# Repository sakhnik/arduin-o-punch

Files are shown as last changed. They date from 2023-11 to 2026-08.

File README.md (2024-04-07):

# Arduin-o-punch

Icon

Arduino-based punching for orienteering with Mifare NFC cards.

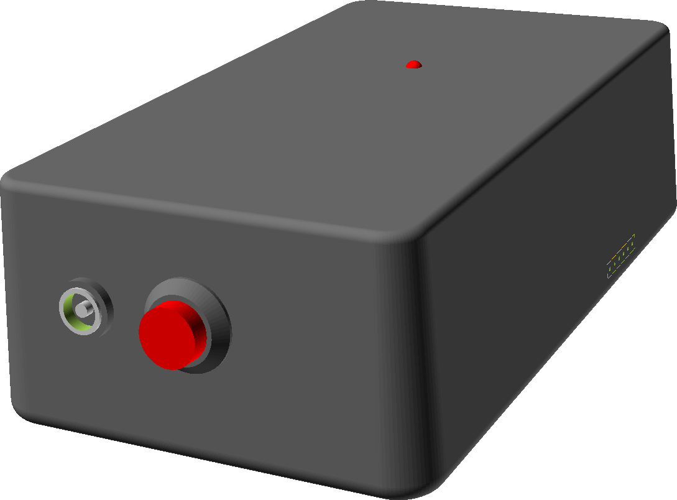
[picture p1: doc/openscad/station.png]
OpenSCAD rendering


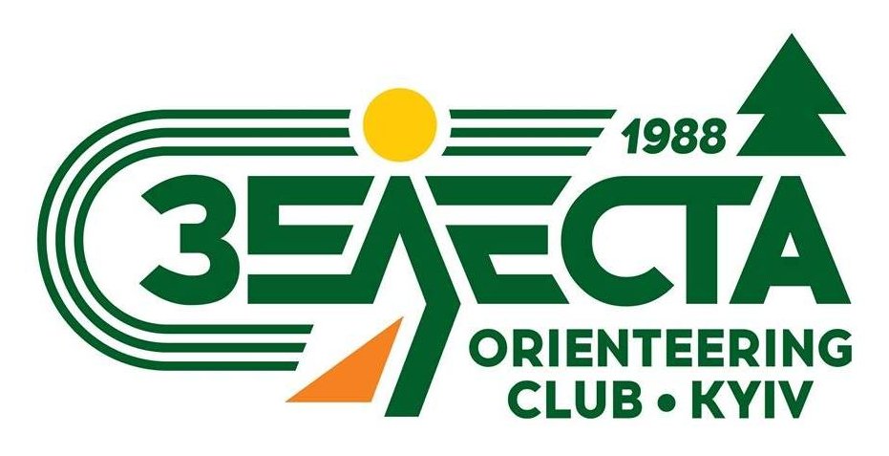
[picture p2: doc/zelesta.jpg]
Зелеста


[Facebook: ZELESTAclub](https://www.facebook.com/ZELESTAclub)

In development. The progress can be followed in the YouTube playlist:
[Arduin-o-punch](https://www.youtube.com/playlist?list=PLd7V290LAw4xda5NdMdNRS0adNVE-jHjh).

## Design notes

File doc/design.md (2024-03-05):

# Arduin-o-punch — custom orienteering punching system built with Arduino

## Components

* MIFARE Classic 1k tags/cards for runners
* Base stations built with Arduino and MFRC 522 RFID reader/writer
* Configuration station: base station + serial interface + PC application
* Android application for card formatting, readout and punches upload:
    [guide](https://developer.android.com/guide/topics/connectivity/nfc/nfc).

## Operation modes

### Arduino station configuration

A high precision RTC clock DS3231 is used backed with CR2032 battery. A station
must be configured with the number, actual crypto key using built in CLI via UART.
Clock is also synchronized with CLI using a scripted application taking into account
communication latency.

The crypto key should ideally be changed on every station before competition, the clocks
are to be synchronized too.

### Signaling

Morse code is used by the base station for signaling. See `Buzzer.cpp` for the actual
list of messages. Most notable are the following ones:

- `OK` upon successful startup
- `RTC` upon startup if communication with RTC fails
- `KEY` upon startup if the default encryption key is used (needs changing)
- `.-` successful punch
- `..-` successful punch of two cards at once
- `...-` successful punch of three cards at once
- `..-.` (Morse `F`) when the card can't be punched because it's full

### Card cleaning and setup

* Authorize with the default key
* Update the key with the actual value for all the blocks
* Write the initial directory index
* Confirm operation successful (beep, flash)

### Card punching

In the MIFARE Classic 1k card, there's only 720 bytes available for punches.
Allocating 4 bytes per punch (1 byte station number + 3 bytes for timestamp in
seconds) allows storing at most 180 punches. The actual limit is lower because
one block should be used for directory information.

It turned out that writing to some cards isn't atomic, the block may be left reset
to all `F`, and the information lost. This prompted for a development of a more
resilient data structure.

The Arduino station records a punch with the following procedure:

- One sector is allocated for a write-ahead log (WAL)
- The log doubles information of the most recent punches (two blocks are used)
- Before punching, the WAL blocks are compared with each other to figure out
  the actual state
- If one of the WAL blocks is missing, it gets restored and written back from
  the healthy one
- When the WAL gets full with 4 punches, the next one triggers copying the punches
  to free storage block (1 copy).
- Add a new punch to the WAL
- Write WAL to the two WAL blocks
- Confirm successful punch

If punching is interrupted at any stage, the data remains consistent. Either
the punching succeeded and the runner got a confirmation, or no confirmation
for her to retry.

The same way Android punching should function for the data consistency.

### Card readout

* Read WAL to find out the actual number of punches
* Read all the punches
* Append the most recent punches from the WAL
* Prepare JSON in the qr-o-punch format, upload to Quick Event
* Confirm successful upload (beep, flash)

### Card reset

Configurator should be used to authorize with the actual key and reset the card
to the pristine state, set default encryption keys in all blocks, reset access
bits.
The application could also track the configured cards to collect statistics
about card states.

## Data layout

See `src/PunchCard.h` for the directory layout, and `src/Punch.h` for the punch data.

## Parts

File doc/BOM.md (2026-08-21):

# Bill of material

| Item | Price | Name | Variant |  Link |
|---|---|---|---|---|
| ESP32-C3 | 88.10 ₴ | | | https://www.aliexpress.com/item/1005006406538478.html |
| RC522 | 44.50 ₴ | MFRC 522 | 1 set | https://www.aliexpress.com/item/1005009711061192.html |
| DS3231SN | 57.00 ₴ | | | https://www.aliexpress.com/item/1005004427508473.html |
| Vibr sensor | 4.00 ₴ | SW-18015P | | https://www.aliexpress.com/item/32952461413.html |
| Buzzer | 12.25 ₴ | | | https://www.aliexpress.com/item/1005004478902150.html |
| Led | 0.30 ₴ | | | https://www.aliexpress.com/item/32985163457.html |
| R1 100K | 0.25 ₴ | | | https://imrad.com.ua/ua/smd1206-100k-1--1 |
| R2 1K | 0.20 ₴ | | | https://imrad.com.ua/ua/1206s4f1001t5e-2 |
| R3 100 | 0.25 ₴ | | | https://imrad.com.ua/ua/rc1206fr-07100rl-0 |
| R4, R5 4K7 | 0.70 ₴ | | | https://imrad.com.ua/ua/rc1206fr-074k7l-1 |
| C1 470uF | 4.00 ₴ | | Low ESR | https://imrad.com.ua/ua/jrg-470u-10-1 |
| C2 1uF | 2.40 ₴ | | | https://imrad.com.ua/ua/cc1206kkx7r9bb105-3 |
| C3 100nF | 2.10 ₴ | | | https://imrad.com.ua/ua/cc1206krx7r9bb104-9 |
| PCB | 42.00 ₴ | | | JLCPCB |
| Bat protection | 7.80 ₴ | | 3.2 Lifepo4 | https://www.aliexpress.com/item/1005001732120817.html |
| Lifepo4 cell | 150.00 ₴ | | | https://prom.ua/ua/p2566621781-akumulyatori-litij-zalizo.html |
| Wires | 11.00 ₴ | 24awg | Y 6x4cm, R+B 10cm | https://www.aliexpress.com/item/1005009794836849.html |

Total        426.85 ₴

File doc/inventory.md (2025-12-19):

# 38

  Battery 18350

  - 2025-11-04 CR2032

# 41

  Battery 18350

 * 2025-11-04 CR2032

# 44

  Battery 18650

  - 2025-11-04 CR2032

# 50

  Battery 18350

  - 2025-11-04 CR2032

# 54

  Battery 18350

  - 2025-11-04 CR2032

# 55 pro16

  Battery 18650

  - 2025-11-06 18650

# 57 pro16

# 58 pro16

# 62 pro16

# 63 pro16

  Battery 18650

  - 2025-11-06 18650

# 64 pro16

# 65

  Battery 18350

  - 2025-11-07 GND contact

# 69

  Battery 18650

  - 2025-11-07 Reglue clock
  - 2025-12-05 Solder GND
  - 2025-12-06 Failure GND - lagging

# 70

  Battery 18650

  - 2025-11-04 leaky battery, clock is off
  - 2025-11-06 18650

# 73

  Battery 18650

  - 2025-12-05 Solder GND

# 74

  Battery 18650

  - 2025-11-04 18650
  - 2025-12-06 Solder GND

# 75

  Battery 18650

  - 2025-11-06 18650

# 76

  Battery 18650

  - 2025-11-06 18650
  - 2025-11-07 CR2032
  - 2025-11-13 GND fix
  - 2025-11-22 Solder GND

# 77

  Battery 18650

# 78

  Hard to flash

# 79

  Battery 18650

  - 2025-11-05 CR2032
  - 2025-11-22 Solder GND

# 100

  Battery 18650

  - 2025-12-05 Solder GND, change 18650, replace CR2032

# 255

  Battery 18650

  - 2025-12-05 Solder GND, replace CR2032, change 18650

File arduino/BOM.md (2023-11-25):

# Bill of material

## Common parts

- RFID RC522
- Active buzzer
- LED
- Power Supply 18650 -> 3.3/5v
- Battery 18650
- Wires

## Arduino options

### Nano

- Arduino Nano 5v 16MHz
- Resistor 220R
- 4x Resistors 2k2
- 4x Resistors 1k

## RTC Clock options

### No RTC

Vulnerable to board reset.

### DS3132

Higher precision (TCOX), higher cost.

- RTC DS3132
- Battery 3.7v LIR2032

# Cost estimate

Arduino   75.00
RC522     50.00
18650     75.00
Power     60.00
DS3231    48.00
Wires      8.00
Buzzer     4.00
Led        1.00
R         10.00
Board      5.00
Box       50.00

Total    386.00

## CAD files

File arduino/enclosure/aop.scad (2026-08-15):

include <BOSL2/std.scad>

$fn = 90;

length = 106;
width = 80;
bottom_thickness = 5;
platform_thickness = 4;
lid_height = 25;
lid_thickness = 5;

battery_d = 18.3;
battery_h = 65.3;
battery_y = 32;

pcb_offset_y = 16;  // back
rfid_offset_y = -25; // fwd
rfid_offset_z = lid_height - lid_thickness;
notch_height = 3;

inner_width = width - 2 * lid_thickness;
inner_length = length - 2 * lid_thickness;
inner_height = lid_height - lid_thickness;
screw_x = width * 0.5 - lid_thickness;
screw_y = length * 0.5 - lid_thickness;

module battery() {
    fwd(battery_y)
    cylinder(h=battery_h, r=battery_d/2, anchor=LEFT, orient=LEFT);
}

module pcb_model() {
    pcb_width = 45.3;
    pcb_length = 55.3;
    pcb_height = 7;
    pcb_hole_r = 0.9;
    pcb_hole_offset = 3;
    pcb_led_offset_y = 6;
    pcb_pad_size = 4;
    pcb_pad_offset = 9;
    pcb_wire_width = 4;

    hole_x = pcb_width * 0.5 - pcb_hole_offset;
    hole_y = pcb_length * 0.5 - pcb_hole_offset;
    pad_x = pcb_width * 0.5 - pcb_pad_offset;
    pad_y = pcb_length * 0.5 - pcb_pad_offset;

    difference() {
        union() {
            cuboid([pcb_width, pcb_length, pcb_height], anchor=BOTTOM);

            // hole for the LED
            fwd(pcb_length * 0.5 - pcb_led_offset_y)
                union() {
                    cylinder(h=lid_height, r=1.6, anchor=BOTTOM);
                    up(lid_height)
                        cylinder(h=1, r=2, anchor=TOP);
                }

            // holes for the pad wires
            move([pad_x, -pcb_length * 0.5, 0])
                cuboid([pcb_wire_width, pcb_wire_width, pcb_height], anchor=BOTTOM+BACK);
            move([pcb_width * 0.5, -pad_y, 0])
                cuboid([pcb_wire_width, pcb_wire_width, pcb_height], anchor=BOTTOM+LEFT);

            // holes for the pads
            move([pad_x, -(pcb_length/2 - pcb_pad_size/2 - 1), 0])
                cylinder(h=lid_height, r=1.72, anchor=TOP);
            move([pcb_width/2 - pcb_pad_size/2 - 1, -pad_y, 0])
                cylinder(h=lid_height, r=1.72, anchor=TOP);
        }

        // holes
        //for (dx = [-1:2:1]) {
        //    for (dy = [-1:2:1]) {
        //        move([dx * hole_x, dy * hole_y, 0])
        //        cylinder(h=10, r=pcb_hole_r);
        //    }
        //}

        // notches
        //left(pcb_width/2) up(notch_height)
        //    cylinder(r=1, h=20, anchor=CENTER, orient=FRONT);
        //right(pcb_width/2) up(notch_height)
        //    cylinder(r=1, h=20, anchor=CENTER, orient=FRONT);
    }
}

module pcb() {
    back(pcb_offset_y) zrot(180) pcb_model();
}

module rfid_model() {
    rfid_width = 40;
    rfid_length = 60.5;
    rfid_height = 5;

    rfid_hole_r = 1.5;
    rfid_hole1_offset = 7.5;
    rfid_hole2_offset_x = 3;
    rfid_hole2_offset_y = 16;

    hole1_x = rfid_width/2 - rfid_hole1_offset;
    hole1_y = rfid_length - rfid_hole1_offset;

    hole2_x = rfid_width/2 - rfid_hole2_offset_x;

    difference() {
        cuboid([rfid_width, rfid_length, rfid_height], anchor=TOP+BACK);

        move([hole1_x, -hole1_y, 0])
            cylinder(h=rfid_height+1, r=rfid_hole_r, anchor=TOP);
        move([-hole1_x, -hole1_y, 0])
            cylinder(h=rfid_height+1, r=rfid_hole_r, anchor=TOP);
        move([hole2_x, -rfid_hole2_offset_y, 0])
            cylinder(h=rfid_height+1, r=rfid_hole_r, anchor=TOP);
        move([-hole2_x, -rfid_hole2_offset_y, 0])
            cylinder(h=rfid_height+1, r=rfid_hole_r, anchor=TOP);

        // notches
        //move([-rfid_width/2, -rfid_length/2, -notch_height])
        //    cylinder(r=1, h=20, anchor=CENTER, orient=FRONT);
        //move([rfid_width/2, -rfid_length/2, -notch_height])
        //    cylinder(r=1, h=20, anchor=CENTER, orient=FRONT);
    }
}

module rfid() {
    move([0, rfid_offset_y, rfid_offset_z])
        zrot(180) rfid_model();
}

module screw_support(x, y) {
    move([x, y, 0])
    cylinder(h=inner_height, r=5);

}

module screw_supports() {
    for (dx = [-1:2:1]) {
        for (dy = [-1:2:1]) {
            screw_support(dx * screw_x, dy * screw_y);
        }
        screw_support(dx * screw_x, 0);
    }
}

module lid_shell() {
    difference() {
        cuboid(
            [width, length, lid_height],
            rounding=5,
            edges=[FRONT+LEFT, FRONT+RIGHT, BACK+LEFT, BACK+RIGHT, TOP],
            anchor=BOTTOM
        );

        down(1)
        cuboid(
            [inner_width, inner_length, 1 + inner_height],
            rounding=5,
            edges=[FRONT+LEFT, FRONT+RIGHT, BACK+LEFT, BACK+RIGHT],
            anchor=BOTTOM
        );
    }
}

module outer_lid() {
    lid_shell();
    screw_supports();
    // battery+rfid support
    up(inner_height)
    cuboid([inner_width, inner_length, platform_thickness], anchor=TOP);
};

module screw_hole(x, y) {
    move([x, y, 0])
    cylinder(h=lid_height-lid_thickness+bottom_thickness, r1=1.72, r2=0.7);

    // Counter sink
    move([x, y, 0])
    cylinder(h=2.5, r1=3.5, r2=1, anchor=BOTTOM);
}

module screw_holes() {
    for (dx = [-1:2:1]) {
        for (dy = [-1:2:1]) {
            screw_hole(dx * screw_x, dy * screw_y);
        }
        screw_hole(dx * screw_x, 0);
    }
}

module lid() {
    difference() {
        outer_lid();

        down(bottom_thickness) screw_holes();
        battery();
        pcb();
        rfid();

        // Optional: a cable hole
        //cable_r = 2.5;

        //left(width/2) back(10) up(platform_thickness + cable_r)
        //union() {
        //    cylinder(h=lid_thickness*2, r=cable_r, orient=LEFT, anchor=CENTER);
        //    cuboid([lid_thickness*2, cable_r*2, bottom_thickness+platform_thickness], anchor=TOP);
        //}
    }
}

module base() {
    difference() {
        union() {
            cuboid(
                [width, length, bottom_thickness],
                rounding=5,
                edges=[FRONT+LEFT, FRONT+RIGHT, BACK+LEFT, BACK+RIGHT],
                anchor=TOP
            );

            cuboid(
                [inner_width, inner_length, platform_thickness],
                anchor=BOTTOM
            );
        }

        screw_supports();
        battery();
        pcb();

        down(bottom_thickness)
            screw_holes();
    }
}

base();

right(100)
    lid();

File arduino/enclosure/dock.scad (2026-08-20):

include <BOSL2/std.scad>

$fn = 90;

module pcb() {

    pcb_length = 30;
    pcb_width = 15.2;

    cuboid([pcb_width, pcb_length, 10], anchor=BOTTOM);

    // usb
    fwd(pcb_length/2 + 2.5) up(0.5)
    cuboid([9.5, 9.5, 3.5], edges=[LEFT+BOTTOM,RIGHT+BOTTOM], rounding=1.4, anchor=TOP+FRONT);

    fwd(1.5) left(3.5)
    cuboid([8.2, 8.2, 4], anchor=TOP);

    back(5)
    cuboid([pcb_width, pcb_length - 10, 2], anchor=TOP);

    back(pcb_length/2)
    cuboid([20, 15, 7], anchor=BOTTOM);

    right(pcb_width/2) back(pcb_length/2-4)
    cuboid([2, 5, 16], anchor=TOP+RIGHT+BACK);
}

difference() {

    back(15)
    cuboid([40, 70, 16], rounding=1.4);

    fwd(2.5)
    pcb();

    left(4) back(55) up(3.5)
    zrot(45)
    cuboid(
        [80, 106, 100],
        rounding=5,
        edges=[FRONT+LEFT, FRONT+RIGHT, BACK+LEFT, BACK+RIGHT],
        anchor=BOTTOM
    );
}

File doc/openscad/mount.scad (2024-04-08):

include <station.scad>

module planck() {
    translate([0, 0, -15])
        cube([bottom_width, bottom_length * 2, 30], center = true);
}

holder_length = 20;
holder_thickness = 2;
holder_depth = 20;

holder_height = height + holder_depth + holder_thickness;

module holder() {
    color("Silver")
        translate([0, 0, holder_height / 2 - holder_depth])
        union() {
            // Overhead bracket
            difference() {
                cube([bottom_width + holder_thickness, holder_length, holder_height], center=true);
                cube([bottom_width, holder_length + 10, holder_height - holder_thickness], center=true);
            }
            translate([0, -holder_length * 0.5, holder_height * 0.5 - holder_depth + holder_thickness * 0.5])
                // Front plate
                difference() {
                    cube([bottom_width, holder_thickness, height], center=true);
                    // Hole for the switch
                    translate([0, holder_thickness, 0]) rotate([90, 0, 0]) cylinder(h = holder_thickness * 4, r = 2);
                    // Hole for the charger plug
                    translate([-bottom_width * 0.2, holder_thickness, 0]) rotate([90, 0, 0]) {
                        hull() {
                            cylinder(h = holder_thickness * 4, r = 5);
                            translate([-8, 0, 0]) cylinder(h = holder_thickness * 4, r = 5);
                        }
                    }
                }
            // Bottom plate (apron)
            translate([0, -holder_length, -holder_depth * 0.5 + holder_thickness])
                cube([bottom_width, holder_length, holder_thickness], center=true);
        }

}

planck();

translate([0, -bottom_length * 0.5 + corner_radius, 0])
    holder();

translate([0, bottom_length * 0.5 - 2 * corner_radius, 0])
    rotate([0, 0, 180]) holder();

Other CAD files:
doc/openscad/station.scad

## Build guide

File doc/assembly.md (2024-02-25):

# How to assemble an Arduino station

[Українською](assembly.uk.md)

| Step | Reference picture |
|---|---|
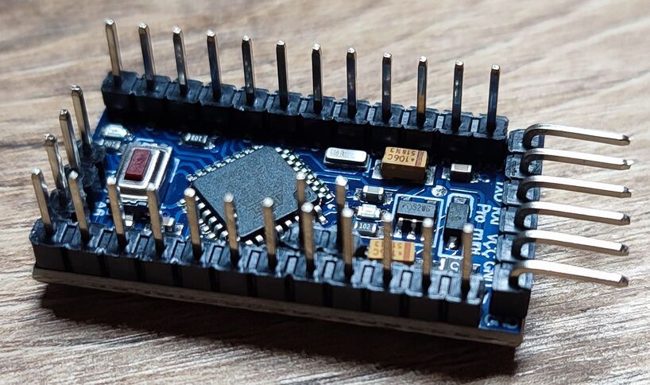
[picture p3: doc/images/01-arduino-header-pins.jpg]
| Solder header pins to the face surface of Arduino Pro Mini  |  |
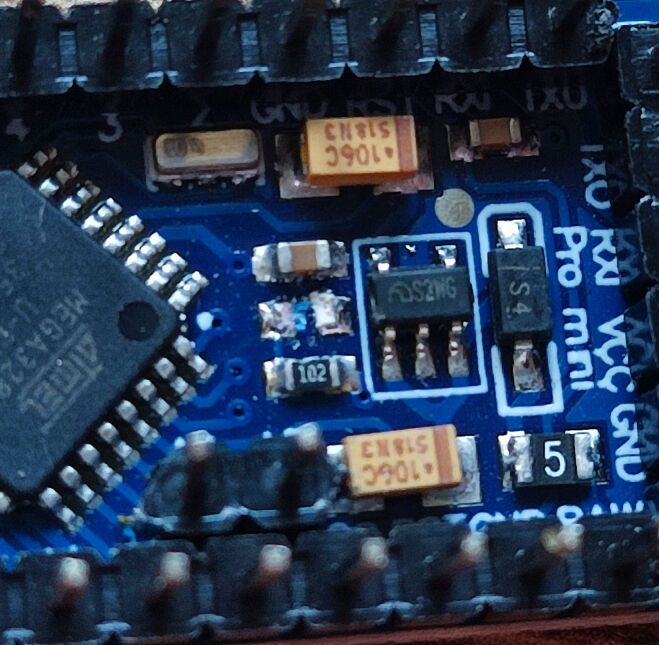
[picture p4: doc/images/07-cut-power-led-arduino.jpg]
| Remove power led from Arduino Pro Mini |  |
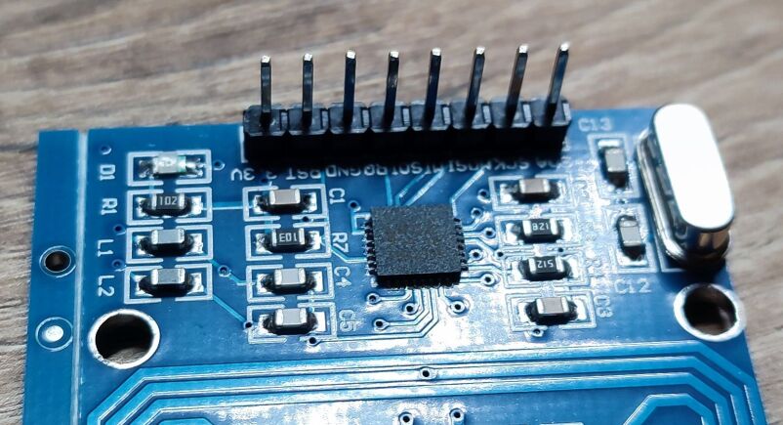
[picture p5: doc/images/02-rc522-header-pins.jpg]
| Solder header pins to the face surface of RC522 |  |
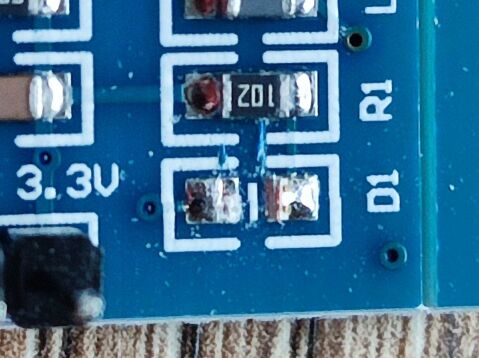
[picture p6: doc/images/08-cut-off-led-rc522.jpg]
| Remove D1 led from RC522 |  |
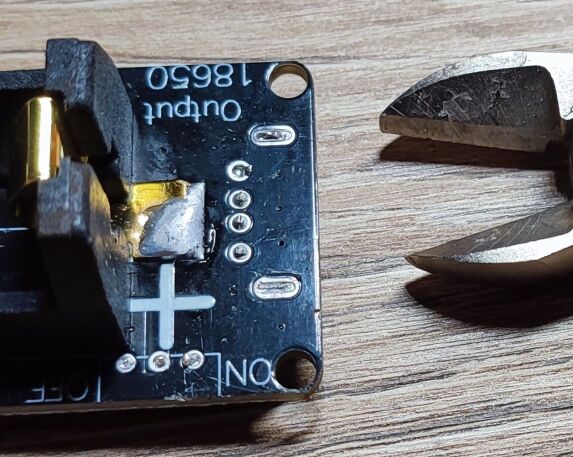
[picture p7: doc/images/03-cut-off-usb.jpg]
| Remove USB output, switch from 18650 power source |  |
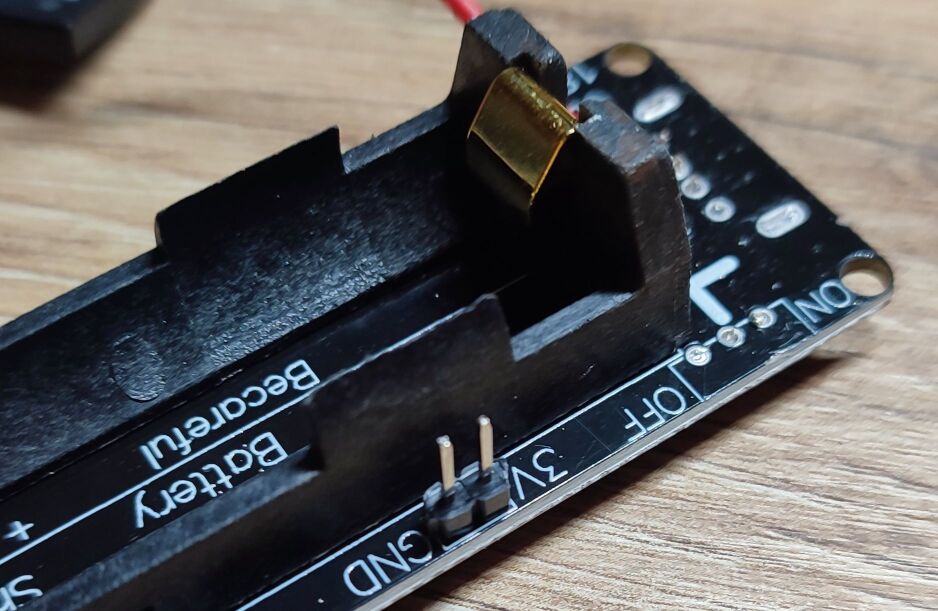
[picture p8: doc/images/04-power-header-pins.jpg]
| Solder header pins to a 3.3v output of 18650 power source |  |
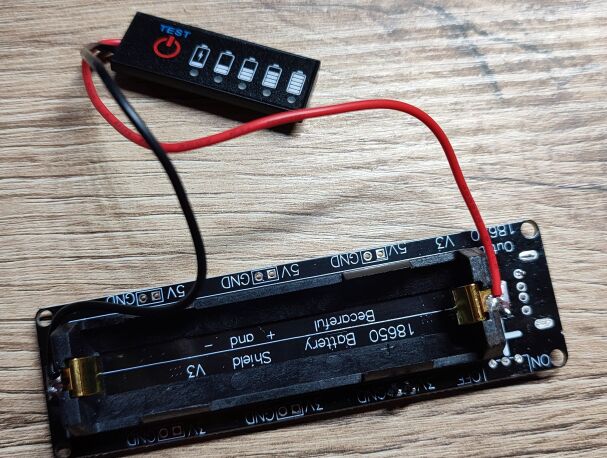
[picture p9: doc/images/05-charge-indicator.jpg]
| Solder indicator to the 18650 pads of 18650 power source |  |
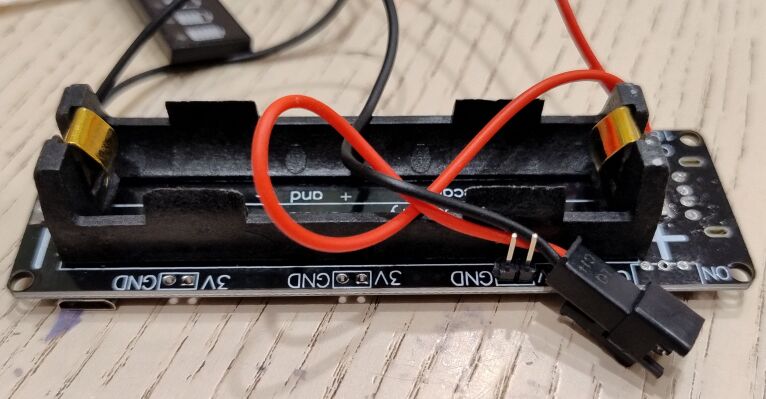
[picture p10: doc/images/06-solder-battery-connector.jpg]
| Solder JST 2-pin battery connector |  |
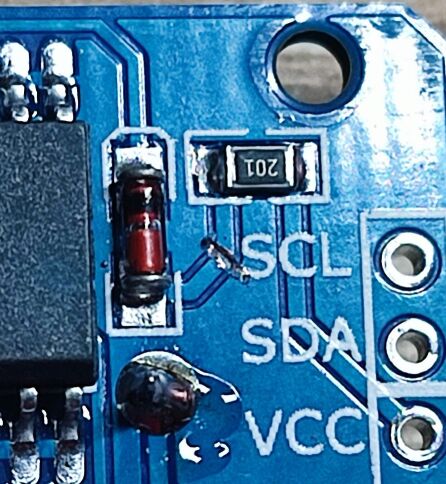
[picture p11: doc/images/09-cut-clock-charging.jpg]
| Cut the charging circuit of DS3231 to allow using non-rechargable CR2032 |   |
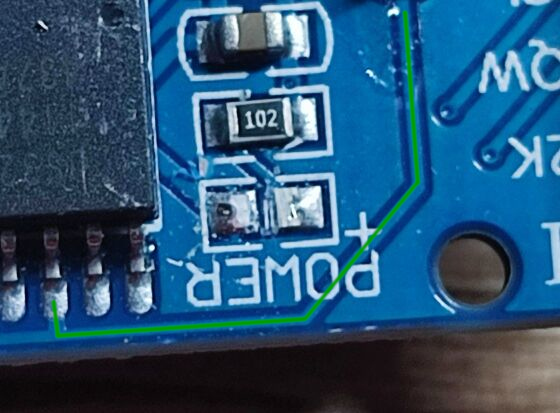
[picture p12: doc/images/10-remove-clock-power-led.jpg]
| Remove power led from DS3231. Be careful not to break the trace from Bat+ to the pin 14 of the IC! |   |
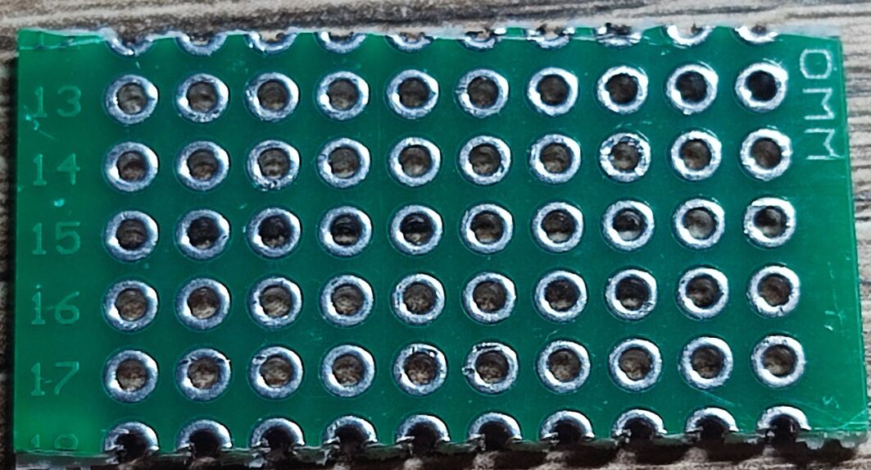
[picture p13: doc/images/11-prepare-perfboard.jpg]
| Prepare perfboard approximately 10x5 holes |  |
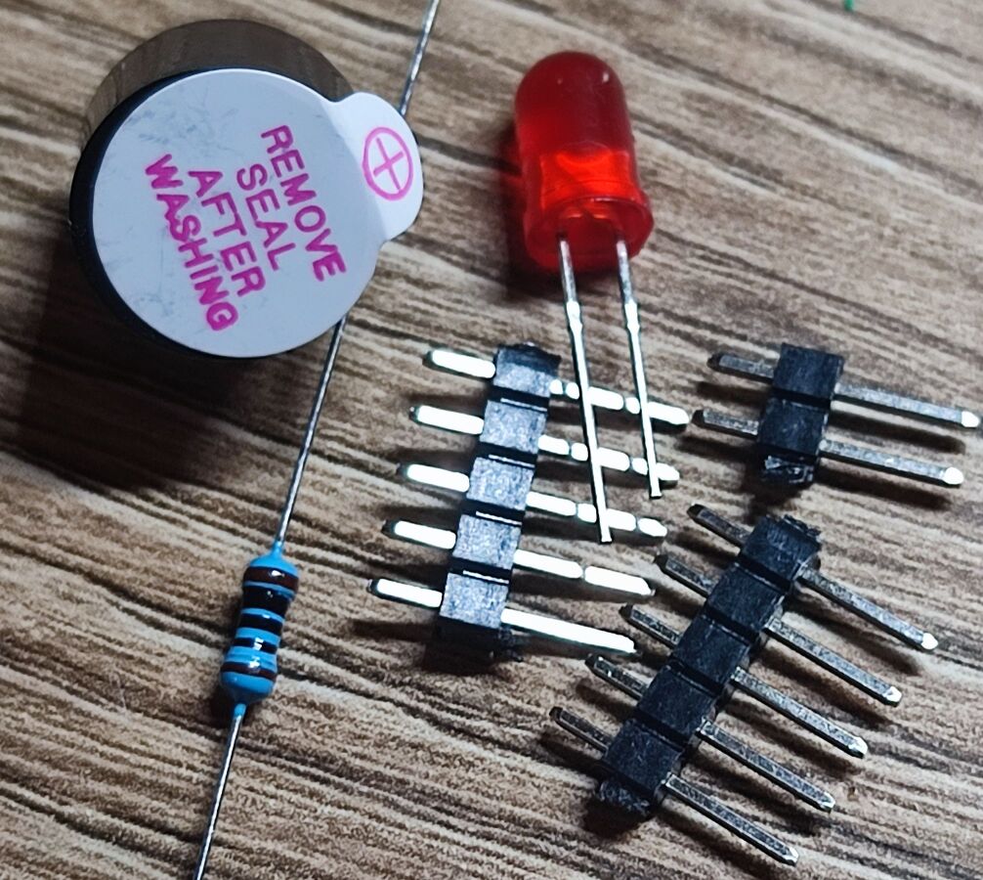
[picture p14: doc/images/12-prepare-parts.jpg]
| Prepare the required parts: led, active buzzer for 3.3v (5v will also work), 100Ω, 2 5x1 pin headers and a pin header 2x1  |   |
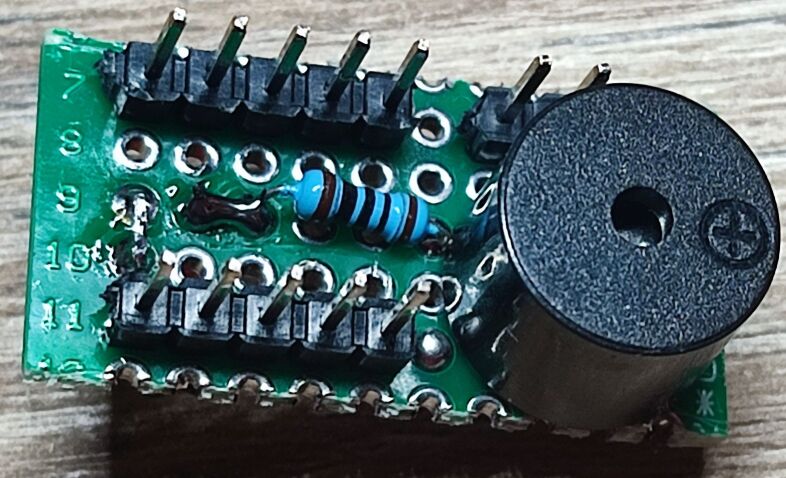
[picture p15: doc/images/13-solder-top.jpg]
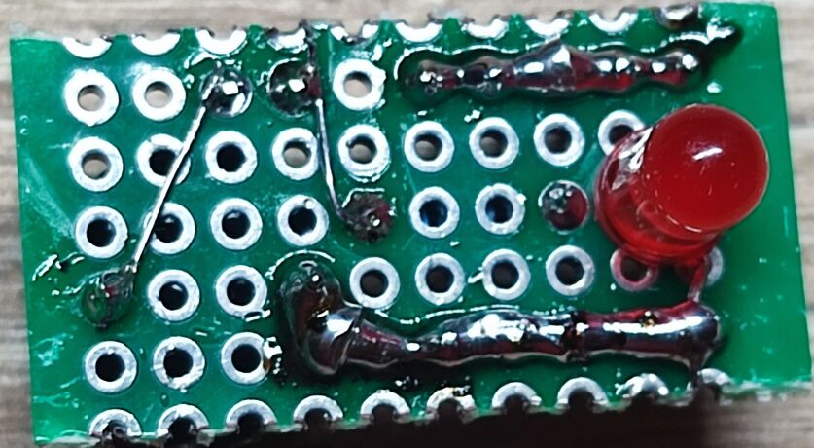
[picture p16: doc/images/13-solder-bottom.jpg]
| Solder the parts onto the perfboard (scheme below) |  |
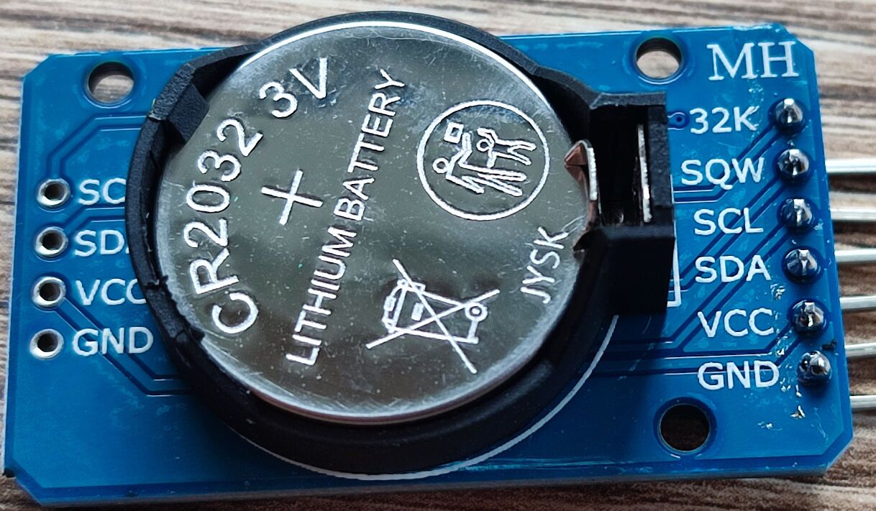
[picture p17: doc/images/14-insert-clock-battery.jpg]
| Insert backup battery CR2032 into the clock module |  |
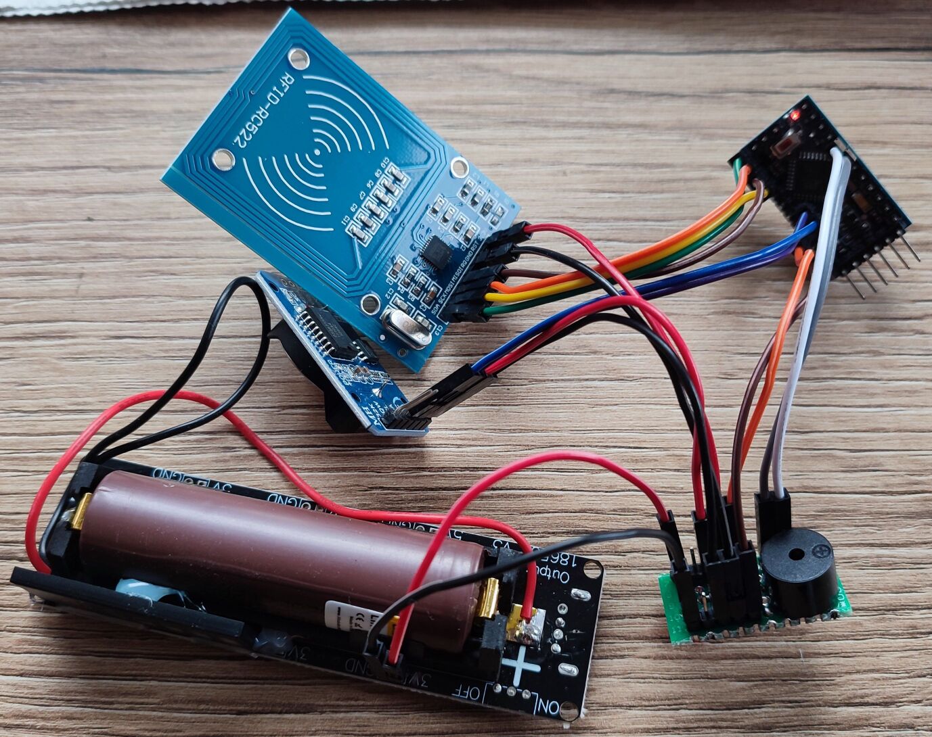
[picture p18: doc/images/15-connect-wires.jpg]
| Connect wires between modules (scheme below) |  |
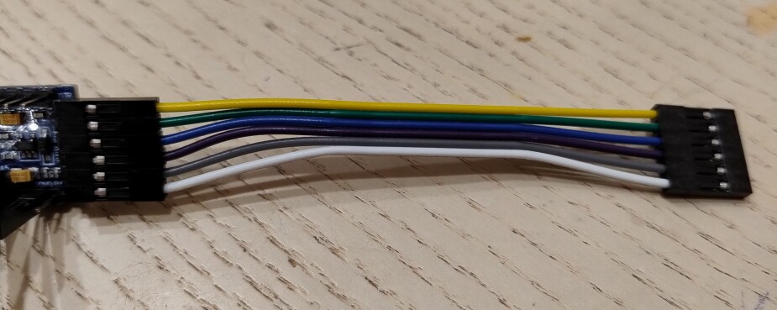
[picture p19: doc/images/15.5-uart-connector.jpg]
| Prepare UART 6P Dupont connector |  |
| Upload the firmware and test (the procedure below) | |

## Soldering scheme

* Two pin headers for negative and positive rails
* Led is placed close to the proximal end on the bottom side, the cathode connected to the negative rail
* Led's anode connected to the resistor 100Ω
* The other end of the resistor to one of the signal pins
* The other signal pin to the positive terminal of the buzzer
* The negative terminal of the buzzer connected to the negative rail

## Wiring scheme

* Clock DS3231: SDA, SCL → A4, A5
* NFC reader RC522: SS, SCK, MOSI, MISO → 10, 13, 11, 12
* Led and buzzer: 4, 5
* All GND to the ground rail of the perfboard with black wires
* All VCC 3.3v to the power rail of the perfboard with red wires
* Power source: GND → ground rail, 3.3v → power rail

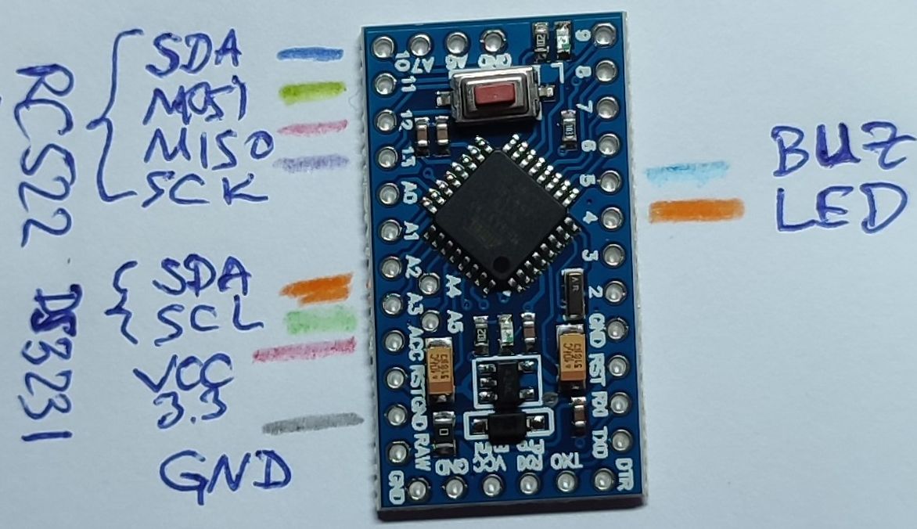
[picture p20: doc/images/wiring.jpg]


The switch the station off, disconnect a wire from the power source.

## Test procedure

* Synchronize the clock
* Configure station id, encryption key
* Punch a test card and verify the punch
* Switch the station off (disconnect from the power source)
* Wait a minute
* Switch the station on
* Check the clock stays set
* Punch a test card and verify the punch

## Encasing

| Step | Reference picture |
|---|---|
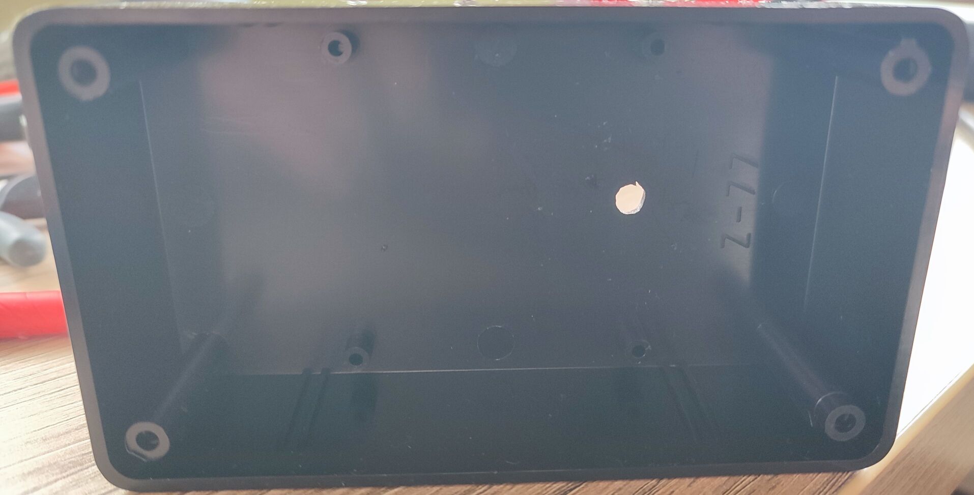
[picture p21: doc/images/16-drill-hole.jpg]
| Drill a hole for LED (3mm or 5mm) |  |
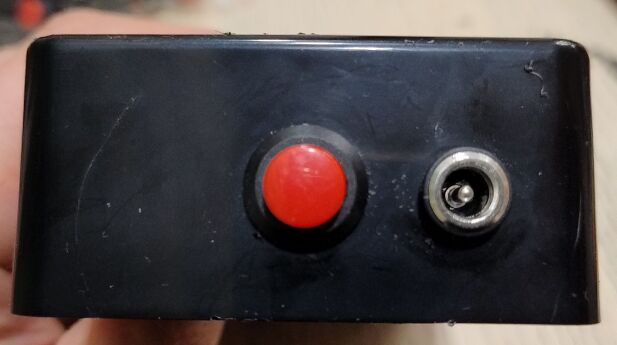
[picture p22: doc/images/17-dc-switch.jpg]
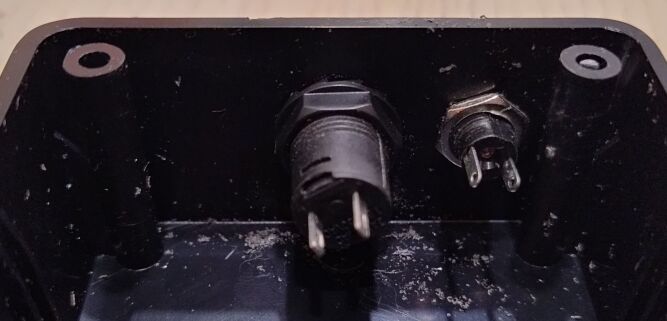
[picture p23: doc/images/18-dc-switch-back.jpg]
| Drill holes for the switch and DC charger input. | <br/>  |
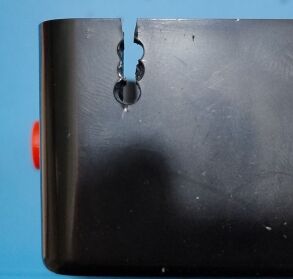
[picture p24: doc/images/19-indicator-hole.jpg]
| Drill and cut a hole for indicator wires |  |
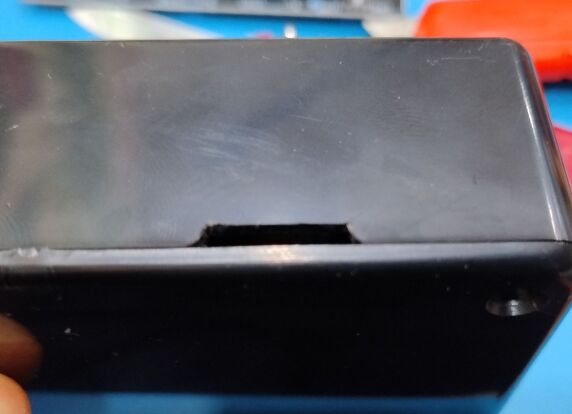
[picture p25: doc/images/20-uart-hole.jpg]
| Cut a hole for UART connector 6P Dupont |  |
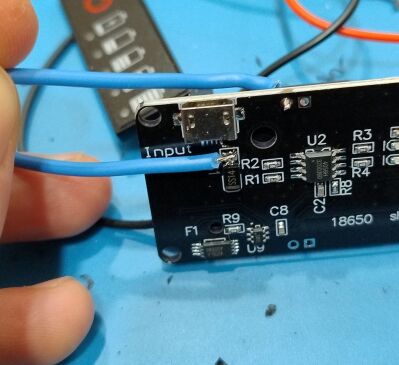
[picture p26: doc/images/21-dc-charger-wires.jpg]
| Solder charger wires GND and 5.2V as shown |  |
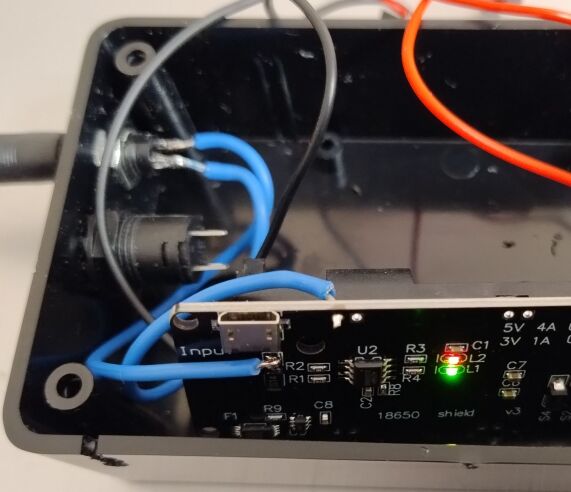
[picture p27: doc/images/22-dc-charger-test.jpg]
| Solder the wires to the DC input and test |  |
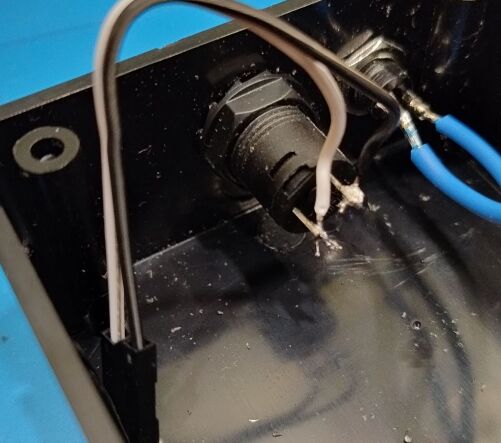
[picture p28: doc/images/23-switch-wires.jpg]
| Solder the connector wires to the switch |  |
| Connect the battery and power lines temorarily and test functionality | |
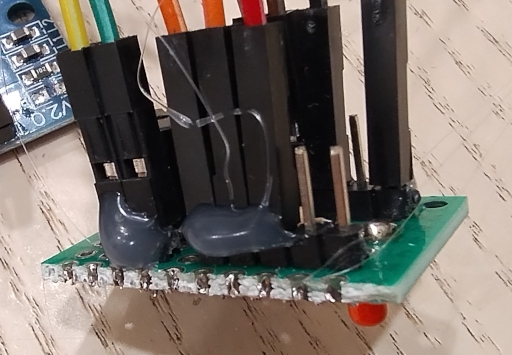
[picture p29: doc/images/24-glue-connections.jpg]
| Fasten Dupont connectors with glue |  |
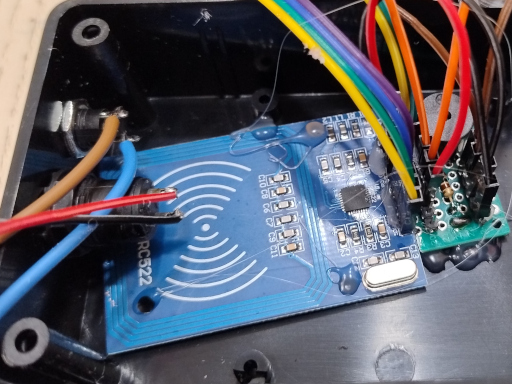
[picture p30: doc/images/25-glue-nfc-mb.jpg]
| Glue NFC reader and motherboard fitting the LED into the hole |  |
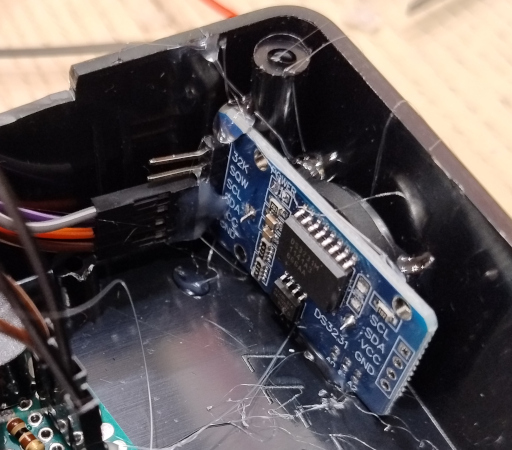
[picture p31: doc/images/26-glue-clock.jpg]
| Glue the clock |  |
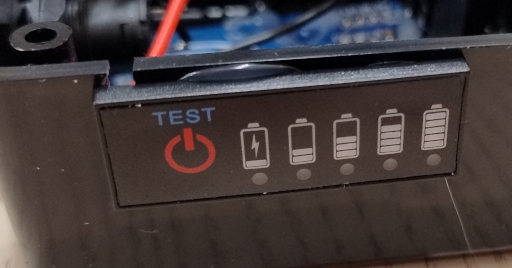
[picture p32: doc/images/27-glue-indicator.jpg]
| Glue power indicator to the outer side |  |
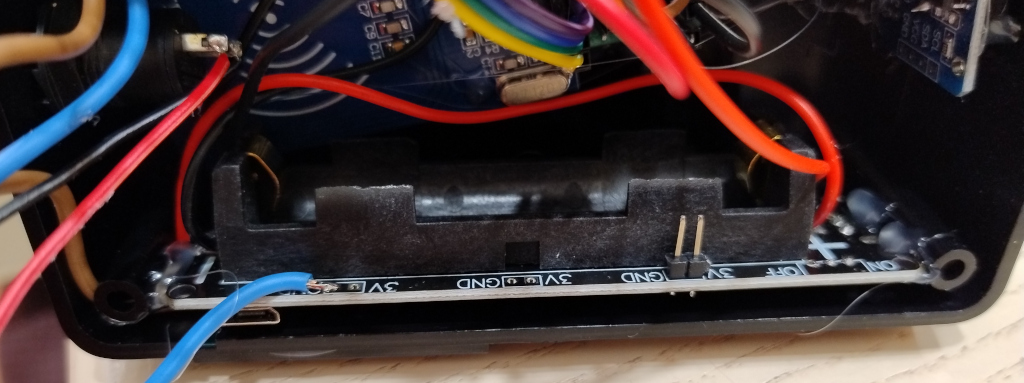
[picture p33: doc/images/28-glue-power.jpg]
| Glue the power adapter |  |
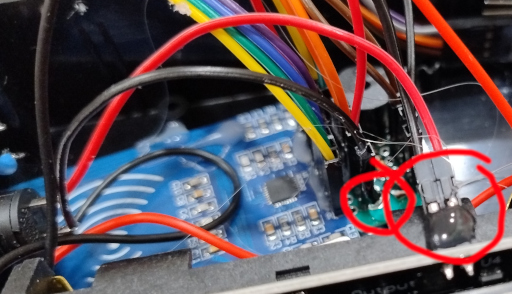
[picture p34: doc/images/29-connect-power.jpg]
| Connect the power lines to the motherboard |  |
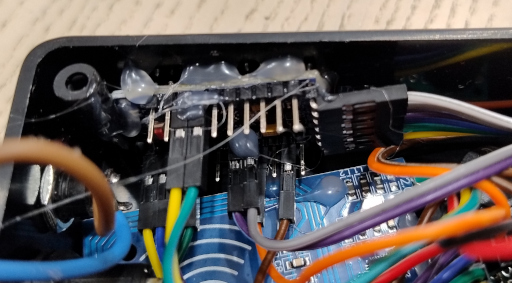
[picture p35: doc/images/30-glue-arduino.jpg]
| Glue the Arduino controller to the side wall |  |
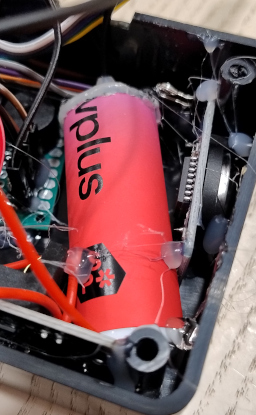
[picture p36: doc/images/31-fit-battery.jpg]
| Fit vape battery into the free space (or insert 18650 into the holder) |  |
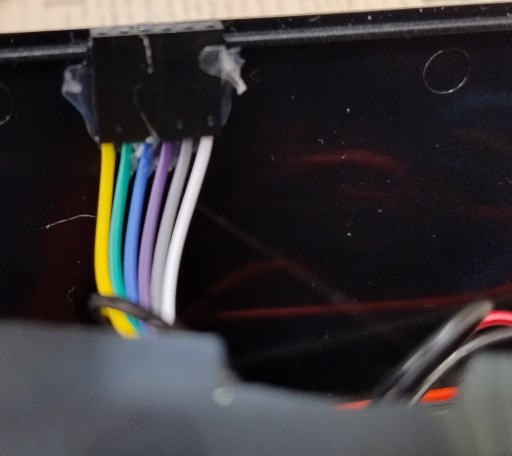
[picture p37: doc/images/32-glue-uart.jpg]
| Glue UART connector to the slit in the lid |  |
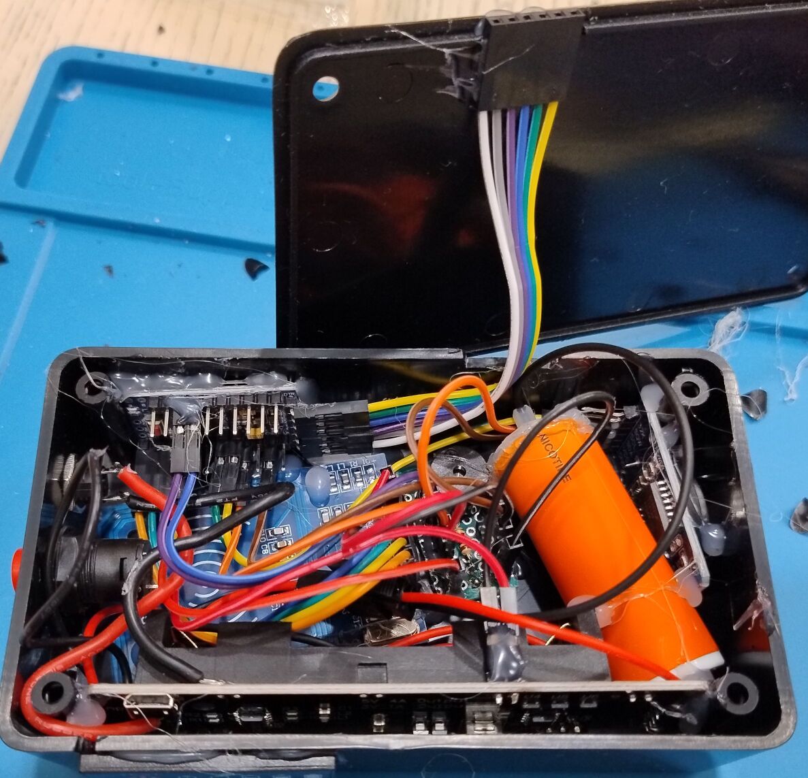
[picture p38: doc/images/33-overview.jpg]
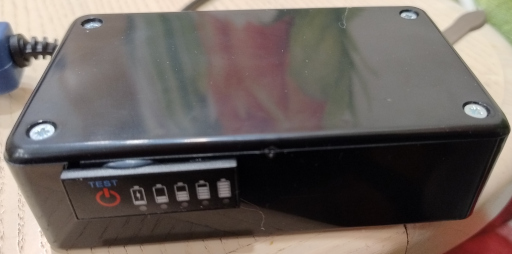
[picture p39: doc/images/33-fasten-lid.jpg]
| Close the lid and fasten with the screws | <br/>  |

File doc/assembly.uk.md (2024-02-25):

# Як зібрати станцію Arduino

[English](assembly.md)

| Крок | Ілюстрація |
|---|---|
| Припаяти виводи на лицевий бік Arduino Pro Mini |  |
| Прибрати індикатор живлення з Arduino Pro Mini |  |
| Припаяти виводи на лицевий бік RC522 |  |
| Прибрати світлодіод D1 з RC522 |  |
| Прибрати вивід USB, вимикач з джерела живлення 18650 |  |
| Припаяти виводи до виходу 3.3 В джерела живлення 18650 |  |
| Припаяти індикатор заряду до полюсів 18650 |  |
| Припаяти конектор JST-2 для під’єднання батареї |  |
| Розірвати ланцюг заряджання DS3231 щоб застосувати незаряджуваний елемент CR2032 |   |
| Прибрати індикатор живлення з DS3231. Обережно, щоб не пошкодити доріжку від Bat+ до виходу 14 мікросхеми! |   |
| Підготувати макетну плату розміром приблизно 10x5 отворів |  |
| Підготувати необхідні деталі: світлодіод, активну пищалку на 3.3 В (5 В також підійде), 100Ω, 2 виводи 5x1 і один вивід 2x1  |   |
| Припаяти деталі на макетну плату (схема нижче) |  |
| Встановити резервний елемент живлення CR2032 в модуль годинника |  |
| З’єднати модулі проводами (схема нижче) |  |
| Підготувати для UART з’єднувач 6P Дюпон |  |
| Вивантажити програму і перевірити (процедура нижче) | |

## Схема паяння

* Два виводи 5х1 для негативної і позитивної шини
* Світлодіод із зворотного боку з ближчого кінця, катодом до негативної шини
* Анод світлодіода до резистора 100Ω
* Інший кінець резистора до одного із сигнальних виводів
* Інший сигнальний вивід до позитивного терміналу пищалки
* Негативний термінал пищалки до негативної шини

## Схема підключення

* Годинник DS3231: SDA, SCL → A4, A5
* Зчитувач NFC RC522: SS, SCK, MOSI, MISO → 10, 13, 11, 12
* Світлодіод і пищалка: 4, 5
* Всі GND до негативної шини макетної плати чорними проводами
* Всі VCC 3.3 В до позитивної шини макетної плати червоними проводами
* Джерело живлення: GND → негативна шина, 3.3 В → позитивна шина



Для вимкнення станції потрібно від’єднати провід від джерела живлення.

## Процедура тестування

* Синхронізувати годинник
* Сконфігурувати номер станції, код шифрування
* Поставити і перевірити відмітку в тестовій картці
* Вимкнути станцію (від’єднати від джерела живлення)
* Зачекати хвилину
* Увімкнути станцію
* Перевірити, чи годинник показує правильний час
* Поставити і перевірити відмітку в тестовій картці

## Монтування у корпус

| Крок | Ілюстрація |
|---|---|
| Просвердлити отвір для світлодіода (3 мм або 5 мм) |  |
| Просвердлити отвори для вимикача і гнізда заряджання. | <br/>  |
| Просвердлити і вирізати отвір для проводів індикатора |  |
| Вирізати отвір для конектора UART 6P Дюпон |  |
| Припаяти проводи заряджання GND і 5.2 В, як на ілюстрації |  |
| Припаяти проводи до входу DC і перевірити |  |
| Припаяти проводи з конектором до вимикача |  |
| Під’єднати тимчасово акумулятор і проводи живлення, перевірити функціональність | |
| Укріпити з’єднувачі Дюпон клеєм |  |
| Приклеїти зчитувачч і материнську плату, просадивши світлодіод у отвір |  |
| Приклеїти годинник |  |
| Приклеїти індикатор заряду акумулятора на зовнішню стінку |  |
| Приклеїти плату живлення |  |
| Під’єднати проводи живлення до материнської плати |  |
| Приклеїти контролер Arduino до бічної стінки |  |
| Встановити акумулятор від електронної цигарки у вільне місце (або вставити 18650 у тримач) |  |
| Приклеїти з’єднувач UART на кришку біля щілини |  |
| Закрити кришку і закріпити шурупами | <br/>  |

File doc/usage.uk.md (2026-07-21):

# Користування Arduin-O-Punch

<a href="https://www.facebook.com/ZELESTAclub">Зелеста</a>

[Facebook: ZELESTAclub](https://www.facebook.com/ZELESTAclub)

Система відмітки [Arduin-O-Punch](https://github.com/sakhnik/arduin-o-punch)
складається із таких частин:

* мобільний додаток на телефоні з андроїдом
* станції розміром 124 х 72 х 32 мм
* перехідник для конфігурації станцій
* картки для відмітки.

Учасники проходять дистанцію із картками і ставлять відмітки на кожному
контрольному пункті, прикладаючи картку до станції.
Мобільний додаток дозволяє підготувати картки учасників на передстартовій
реєстрації та зчитати і надіслати результати після фінішу для обробки у програму
[o-event](https://github.com/sakhnik/o-event).

Система змодельована за принципом SPORTIndent, проте є деякі відмінності.

## Технічні характеристики системи

| Параметр | Значення |
|---|---|
| Робоча напруга схеми  | 3.3 В |
| Час роботи станції від повністю зарядженого акумулятора 3000 мА·г | ~7 днів |
| Роздільна здатність годинника  |  1 сек  |
| Точність годинника | 3.5 ppm ~ 0.3 сек/день |
| Максимальна кількість відміток на картці | 184 |
| Максимальна кількість записів у станції  | 32000 (до 1 підходу)<br/>16000 (до 3 підходів)<br/>8000 (до 15 підходів) |
| Температурний діапазон | 0–40 °C |

## Учасникам

Під час реєстрації видається стартовий номер, який буде використаний у картці
відмітки для ідентифікації учасника. Організатори підготують і видадуть готову
до проходження дистанції картку під час мандатної комісії.

Для успішного проходження дистанції потрібно очистити попередню відмітку перед стартом,
відмітитися на старті, потім на всіх контрольних пунктах дистанції у заданому
порядку (або й ні залежно від умов змагань), нарешті на фініші.

Відмітка записується у картку шляхом піднесення до цифр на коробці станції
до отримання звукового і видимого підтвердження. Учасник повинен впевнитися,
що отримав відмітку.

Результат зчитують після фінішу секретарі змагань з допомогою мобільного додатку
Android. Він автоматично вивантажується у програму o-event для обробки і
відразу видається друкована квитанція. Відмітка продовжує зберігатися на картці
до наступного старту.

## Організаторам

### Підготовка станцій до змагань

* Вибрати таємний ключ шифрування 12 шістнадцяткових цифр (0–9, A–F).
* Підготувати тестову картку з допомогою мобільного застосунку Android

Для кожної станцій виконати такі дії:

* Зарядити акумулятори станцій або переконатися з допомогою індикатора, що вони заряджені
* Під’єднати перехідник, перевірити і виправити налаштування:
  - Номер станції має відповідати маркуванню
  - Задати і перевірити ключ шифрування
  - Підготувати журнал відмітки для очікуваної кількості учасників
  - Синхронізувати годинник
* Перевірити правильність відмітки на тестовій картці
* Вимкнути станцію для заощадження заряду

### Розміщення станцій у контрольних пунктах

* Увімкнути станцію
* Прикріпити станцію на рейку
* Перевірити правильність відмітки на тестовій картці

### Підготовка карток перед стартом

* Визначити номер учасника в програмі QuickEvent. Він має співпадати із ідентифікатором чипа
* Відкрити розділ «Підготувати картку бігуна» в застосунку Android
* Задати номер учасника в текстовому полі або відсканувати QR-код реєстрації
    учасника з QuickEvent
* Прикласти чисту картку до телефону і пересвідчитися, що прогрес дійшов до
    кінця і закінчився успішно
* Позначити картку наліпкою із підписаним номером для зручності учасника.

Для зменшення черги учасників можуть обслуговувати кілька секретарів одночасно.

### Зчитування відміток для обробки

* Відкрити розділ «Прочитати картку бігуна» в застосунку Android
* Поставити відмітку «Вивантажити», задати адресу
    `http://o-event.lan:12345/card`
* Прикласти картку учасника до телефону і дочекатися закінчення зчитування і
    вивантаження

### Після збору станцій

* При потребі під’єднати перехідник-програматор, щоб отримати список відмічених
    карток або щоб перевірити підхід певного учасника
* Вимкнути станцію для заощадження заряду

### Відновлення карток після змагань

* Відкрити розділ «Скинути картку бігуна» в застосунку Android
* Піднести по черзі кожну картку, щоб скинути записаний ключ шифрування у
    початковий стан

Карток може бути багато, тому для краще це виконувати кількома телефонами
одночасно.

## Функціональні частини системи

### Мобільний додаток Android

Початковий код знаходиться у директорії `android`. Додаток можна скласти у
Android Studio. Він не опублікований у Play Marker або деінде. Проте готову
копію можна завантажити за посиланням
[https://sakhnik.com/aop.apk](https://sakhnik.com/aop.apk).

Додаток працює із картками: готує до старту, скидає або ставить відмітку (для
перевірки), зчитує відмітку і скидає картку в початковий стан. Для виконання
будь-якої з цих дій потрібно вибрати відповідну сторінку в лівій панелі, ввести
бажані параметри у відповідні поля і піднести картку до зворотного боку
смартфону. Успішну операцію підтверджує звуковий сигнал. Якщо ж картку
передчасно забрати або стається будь-яка інша помилка, буде подано сигнал
помилки і на екрані з’явиться коротке повідомлення з подробицями.

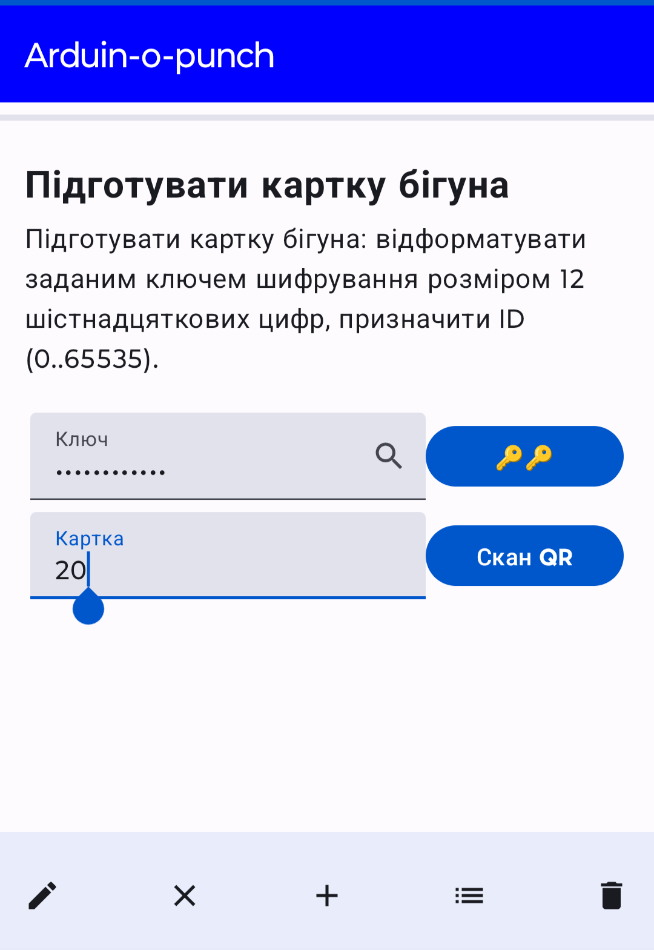
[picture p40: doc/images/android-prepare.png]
Prepare Card

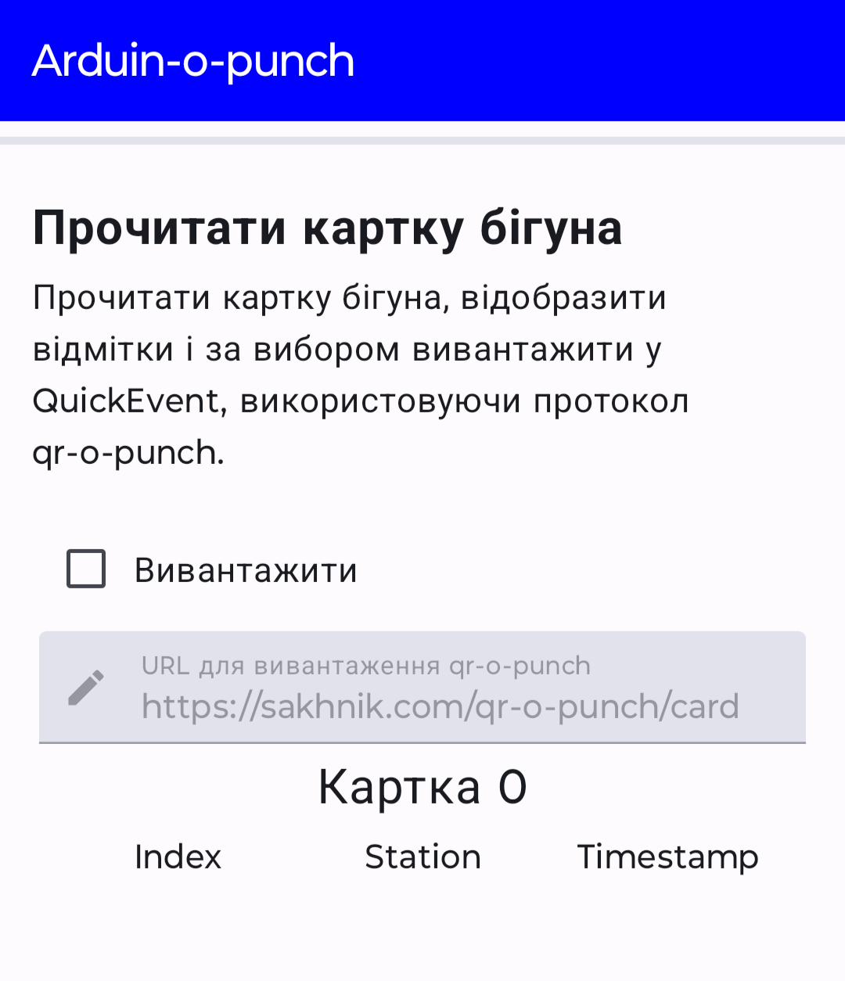
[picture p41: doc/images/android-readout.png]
Read out


### Станція Arduin-o-punch

Це чорна закрита коробка із такими частинами:

* Вимикач
* Вхід для заряджання 5 В 5,5х2,1 мм
* Індикатор заряду акумулятора
* Гніздо для приєднання програматора USB-UART
* Світлодіод для індикації
* Пищалка всередині корусу, яка повторює сигнали світлодіода
* Безконтактний зчитувач карток NFC Mifare

### Акумулятор

Для заряджання акумулятора потрібно під’єднати зарядний пристрій до гнізда
заряджання DC 5,5х2,1 мм.

Рівень заряду акумулятора можна перевірити, натиснувши на кнопку увімкнення
індикатора.

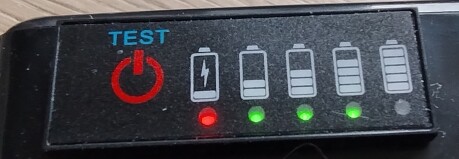
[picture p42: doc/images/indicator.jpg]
Battery indicator


### Програмування

Arduino Pro Mini, використаний у базовій станції, не має власного виходу USB.
Під’єднання до комп’ютера для програмування чи конфігурування здійснюється з
допомогою програматора-перехідника USB-UART. Під час під’єднання перехідника
контролер перевантажується.

USB-UART

Мікропрограма збирається з допомогою [PlatformIO](https://platformio.org).

### Командна оболонка

До запрограмованої станції при під’єднаному акумуляторі можна під’єднатися через
послідовний порт `/dev/ttyUSB0` у Linux з допомогою команди `screen /dev/ttyUSB0
9600` або скористатися будь-якою іншою термінальною програмою. При під’єднанні
контролер перевантажується і демонструє запрошення ввести команду:

```
Arduin-o-punch>
```

Перша команда, яку потрібно знати, `help`:

```
Arduin-o-punch> help
Commands:
info              All info
id                ID
id 33             Set ID: check=1 start=10 finish=255
key               Key
key 112233445566  Set key
clock             Clock reading (ms)
clock 12345000    Set clock (ms)
date              Current date
time              Current time
timestamp         Print UNIX timestamp
timestamp 12345   Set date and time with UNIX timestamp
recfmt 256 2      Clear/prepare recorder (card count, bits per record)
rec               List punched cards
rec 123           Print punch count for a card
recclr 123        Clear card from the record
recdays           How many days to keep the record
recdays 1         Clear record after so many days
Arduin-o-punch>
```

Це підказка із списком підтримуваних команд і їхніх аргументів.
Друга важлива команда — `info`:

```
Arduin-o-punch> info
version=1.1.1
id=41
key=112233445566
date=2024-02-18
time=13:57:58
rec=256 x 2 bpr
recdays=1
Arduin-o-punch>
```

Вона друкує актуальний статус станції: версію програми, номер станції, ключ
шифрування, час годинника, розмір журналу відмітки. Про всі ці команди
детальніше в наступних розділах.

Для виходу з програми `screen` потрібно натиснути `ctrl-a`, ввести команду
`:quit` і натиснути `enter`.

### Номер станції

Номер станції — це число від 0 до 255. Воно записується в картку разом із
поточним часом щоб поставити відмітку. Деякі номери зарезервовані і мають
спеціальне значення:

|  Номер  | Значення  |
|---|---|
| 1 | Станція перевірки (зарезервовано) |
| 10 | Старт (попередня відмітка скидається) |
| 255 | Фініш |

Будь-який інший номер можна використати для контрольного пункту. Традиційно
застосовують номери 31, 32, 33,… , 100.

Для перевірки номера станції і задання нового потрібно використати команду `id`:

```
Arduin-o-punch> id
41
Arduin-o-punch> id 45
45
Arduin-o-punch>
```

## Ключ шифрування

Інформація на картці захищена від запису сторонніми програмами ключем довжиною
12 шістнадцяткових цифр. Це стандартна можливість карток Mifare. На кожний захід
потрібно обирати новий ключ, щоб убезпечити результат змагань від підробки.
Справді, будь-хто, хто знає ключ шифрування може скористатися застосунком
Android, щоб поставити потрібні відмітки на свою картку. З іншого боку судді
повинні знати ключ шифрування, щоб готувати картки перед змаганнями, зчитувати
результати для надсилання їх для обробки і для відновлення карток в початковий
стан після фінішу.

Для конфігурування станції слід скористатися командою `key`:

```
Arduin-o-punch> key
FFFFFFFFFFFF
Arduin-o-punch> key 112233445566
112233445566
Arduin-o-punch>
```

При зміні ключа станція подає сигнал успішної відмітки.

### Годинник

Щоб мати надійні достовірні результати потрібно щоб всі станції працювали
синхронно, тобто щоб годинники у станціях показували однаковий час. Взагалі-то,
це не є геть обов’язковою умовою. Наприклад, якщо всі учасники отримують
стартову і фінішну відмітку на одних і тих самих станціях, лідери так само
залишаться лідерами в підсумку. Навіть незважаючи на, можливо, неправильні
значення темпу. Проте якщо всі станції показують однаковий час, тоді можна
отримати правильний розрахунок темпу при відвідуванні кожного контрольного
пункту.

Станції послуговуються точним годинником справжнього часу з резервним елементом
живлення CR2032, заряду якого має вистачити на кілька років.

Для синхронізації годинника потрібно під’єднати програматор і запустити на
комп’ютері скрипт `sync-сlock.py`.

```
$ virtualenv /tmp/venv
created virtual environment CPython3.11.6.final.0-64 in 501ms
  creator CPython3Posix(dest=/tmp/venv, clear=False, no_vcs_ignore=False, global=False)
  seeder FromAppData(download=False, pip=bundle, setuptools=bundle, wheel=bundle, via=copy, app_data_dir=/home/sakhnik/.local/share/virtualenv)
    added seed packages: pip==23.3.2, pyserial==3.5, setuptools==69.0.3, wheel==0.42.0
  activators BashActivator,CShellActivator,FishActivator,NushellActivator,PowerShellActivator,PythonActivator

$ source /tmp/venv/bin/activate

venv $ pip install -r requirements.txt
Requirement already satisfied: pyserial in /tmp/venv/lib/python3.11/site-packages (from -r requirements.txt (line 1)) (3.5)

venv $ ./sync-clock.py
>> b''
>> b'\r\n'
>> b'Arduin-o-punch> '
>> b'37103085\r\n'
Before: clock=37103085 time=10:18:23
>> b'1708942704\r\n'
After: 2024-02-26 10:18:24

venv $
```

Для роботи у операційній системі Windows, потрібно вказати порт `COM5`:

```
PS> python ./sync-clock.py -p COM5
>> b''
>> b'\r\n'
>> b'Arduin-o-punch> '
>> b'37103085\r\n'
Before: clock=37103085 time=10:18:23
>> b'1708942704\r\n'
After: 2024-02-26 10:18:24
```

Цей самий скрипт `sync-clock.py` можна використовувати для масового
конфігурування станцій. Для цього йому можна задати додатковий аргумент
`--script s.txt` із списком команд, які буде виконано після синхронізації
годинника. Також номер станції можна встановити з допомогою параметра `--id`.

```
$ cat s.txt
key 112233445566
recfmt 512 2
$ ./scripts/sync-clock.py --script s.txt --id 42
>> b''
>> b'\r\n'
>> b'Arduin-o-punch> '
>> b'65481118\r\n'
Before: clock=65481118 time=18:11:21
>> b'1710958284\r\n'
After: 2024-03-20 18:11:24
>> b'42\r\n'
key 112233445566
>> b'112233445566\r\n'
recfmt 512 2
>> b'OK\r\n'
```

### Журнал відмітки

Записування відмічених карток у станції може знадобитися для додаткового
підтвердження відмітки. Для активування цієї функції потрібно оцінити очікувану
кількість учасників (максимальний стартовий номер) і кількість підходів одного
учасника на цей конкретний контрольний пункт. Наприклад, у центральній точці
«метелика» очікується кілька відвідувань.

```
recfmt <найбільший номер> [1|2|4|8]
```

| Кількість бітів | Кількість підходів | Максимальний стартовий номер |
|---|---|---|
| 1 | 0–1 |  8000  |
| 2 | 0–3 |  4000  |
| 4 | 0–15  |  2000  |
| 8 | 0–255 |  1000  |

Кількість бітів потрібно вибирати ощадливо, тому що кількість циклів записування
у внутрішню пам’ять обмежена приблизно 10000 разів.

Журнал очищується автоматично при увімкненні станції після `recdays` днів:
```
Arduin-o-punch> recdays
0
Arduin-o-punch> recdays 1
1
Arduin-o-punch>
```
Значення 0 означає не очищувати журнал автоматично, 1 очищувати, якщо станція
вмикається на наступний день після попереднього очищення, 2 — через два дні і
так далі. Це може знадобитися для багатоденних змагань, щоб не доводилося
очищувати журнал командою програматора `recfmt`.

Щоб вивести список відмічених карток, можна скористатися командою `rec`:
```
Arduin-o-punch> rec
Size=256
 90:1 91:1 92:1 93:1 123:1
Arduin-o-punch>
```

Щоб перевірити, скілька разів було відмічено одну певну картку, та сама команда
тільки з аргументом `rec 123`.
```
Arduin-o-punch> rec 123
1
Arduin-o-punch>
```

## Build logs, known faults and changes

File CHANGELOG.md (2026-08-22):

# Changelog

All notable changes to this project will be documented in this file.

The format is based on [Keep a Changelog](https://keepachangelog.com/en/1.1.0/),
and this project adheres to [Semantic Versioning](https://semver.org/spec/v2.0.0.html).

## [Unreleased]

### Added

- Eco mode after inactivity period
- Deep sleep after inactivity period, wake up on shake
- ArduinoOTA
- Debug card to retrieve diagnostic information
- UART for programming, configuration and debugging instead of USB CDC
- Card readout, formatting via shell
- Cyclic card formatting, reading previous run punches
- Dedicated station for clearing punches before the start
- Station configuration in the android App via BLE
- BLE OTA update
- Self-test during startup

### Changed

- License GPL v2
- FreeRTOS instead of cooperative loop
- Decrease CPU frequency to 10 MHz
- Store settings as non-volatile preferences
- Switch off BLE and WiFi after a 2-minute inactivity timeout
- Start station doesn't clear the punches
- Punch record will keep the time of the individual punches
- WiFi capability is optional during build time
- OK (punch mode) just `dit` (E)

### Removed

- Use of external EEPROM
- Clearing punches in the Android app

## [2.1.0] - 2025.11.30

### Added

- Service card to cycle through operation, Bluetooth and WiFi modes
- Bluetooth server for configuration
- TCP server on port 23 over WiFi for configuration
- Web app for configuration and OTA firmware update
- Signal last octet of IP address in Morse
- Android: long tap on the selector locks the view
- Android: allow selecting and copying punches to the clipboard
- Android: export/import settings
- Android: about dialog with version and git revision

### Changed

- Building firmware with platformio
- Ported Android app to Jetpack Compose
- Arduino: display the bytes of unknown command
- Android: remove the word "runner" from every page
- Arduino: soft reset MFRC522 periodically

### Removed

- Key display in `info`
- Navigation menu from Android app, using icon buttons instead

## [2.0.0] - 2024.04.29

### Added

- Continuous integration in GitHub workflow
- Web app to test the card layout (built from the actual code with emsdk)
- Automatic DST adjustment for EEST rules
- Tested programming and configuration in Windows, added instructions
- Added arguments to sync-clock.py to change serial port and to execute command script
- OpenSCAD model of the station and suggested a mount

### Changed

- **New data structure** resilient to information loss due to failed writes on some cards
- Use external EEPROM AT24C32 onboard DS3231 RTC
- Fix latency calculation in sync_clock.py, wait for the prompt explicitly
- Fix layout in Android app for smaller screens
- Keep current view when the screen is rotated
- Fix the capacity number
- Fix crash when garbage in the timestamp
- Allow entering key with lower case hex digits too
- Don't record a duplicate punch on the station

## [1.1.0] - 2024.02.24

### Added

- Try previous keys in Android to facilitate card preparation and resetting
- Lock upload URL to prevent accidental modification
- Successful startup confirmation (OK = --- -.-)
- Set both date and time with UNIX timestamp
- Record retaining period in days

### Changed

- Fix finish control uploading: shouldn't be uploaded, the number should be 900 in QuickEvent
- Fix start time by the *last* start control punch
- Prototype casing with DC input, switch and programmator connector
- Fix DNF when finish wasn't punched (finishTime = 0xEEEE)
- Use arduino clock for millisecond measurement of clock during synchronization

### Removed

- Batteries from the BOM (can use recycled ones from wapes)
- Time measurement from custom point, always from midnight
- Sleeping on timeout in favour of the power off button

## [1.0] - 2024-01-27

### Added

- First 10 prototypes with open casing

[Unreleased]: https://github.com/sakhnik/arduin-o-punch/compare/v2.1.0...HEAD
[2.1.0]: https://github.com/sakhnik/arduin-o-punch/compare/v2.0.0...v2.1.0
[2.0.0]: https://github.com/sakhnik/arduin-o-punch/compare/v1.1.0...v2.0.0
[1.1.0]: https://github.com/sakhnik/arduin-o-punch/compare/v1.0...v1.1.0
[1.0]: https://github.com/sakhnik/arduin-o-punch/releases/tag/v1.0

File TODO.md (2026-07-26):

Arduino:

  - Card reset in arduino
  - Add special card to put stations to sleep
  - Improve clock synchronization precision (-100 ms via BLE currently)
  - Add a way to add more previous keys (line length is currently limited)

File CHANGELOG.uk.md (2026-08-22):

# Журнал змін

В цьому файлі буде задокументовано всі помітні зміни в цьому проєкті.

Формат засновано на [Keep a Changelog](https://keepachangelog.com/en/1.1.0/),
і цей проєкт використовує [Semantic Versioning](https://semver.org/spec/v2.0.0.html).

## [Невипущене]

### Додано

- Режим економії після періоду неактивності
- Глибокий сон після періоду неактивності, пробудження від струсу
- ArduinoOTA
- Картка налагодження для отримання діагностичної інформації
- UART для програмування, конфігурування і налагодження замість USB CDC
- Зчитування, форматування картки через оболонку
- Циклічне форматування картки, зчитування відміток попередніх стартів
- Окрема станція очищення попередніх відміток перед стартом
- Конфігурування станції в додатку Android через BLE
- Поновлення через BLE
- Автодіагностика при запуску

### Змінено

- Ліцензія GPL v2
- FreeRTOS замість кооперативного циклу
- Зменшено тактову частоту до 10 МГц
- Зберігання налаштувань як Preferences в NVS
- Вимкнення BLE і WiFi після 2 хв простою
- Стартова станція не видаляє попередні відмітки
- Журнал відміток зберігатиме час кожної відмітки
- Функціональність WiFi може бути увімкнено під час компіляції
- OK (режим відмітки) просто `ті` (E)

### Видалено

- Використання зовнішьої пам’яті EEPROM
- Очищення відміток у додатку Android

## [2.1.0] - 2025.11.30

### Додано

- Службову картку для вибирання режиму: робочий, Bluetooth, WiFi
- Сервер Bluetooth для налаштування станції
- Сервер TCP (порт 23) через WiFi для налаштування
- Веб застосунок для конфігурування і поновлення мікропрограми
- Повідомлення останнього октету адреси IP азбукою Морзе
- Android: довге натиснення на селекторі фіксує функцію
- Android: виділення і копіювання відміток у буфер обміну
- Android: експортування й імпортування налаштувань
- Android: діалог з інформацією про версію і ревізію git

### Змінено

- Збирання мікропрограми з platformio
- Портовано застосунок Android на Jetpack Compose
- Arduino: друк байтів невідомої команди
- Android: видалено слово «бігуна» на кожній сторінці
- Arduino: періодичне програмне скидання MFRC522

### Видалено

- Відображення ключа в `info`
- Навігаційне меню із застосунку Android, натомість додано кнопки

## [2.0.0] - 2024.04.29

### Додано

- Безперервну інтеграцію в GitHub
- Веб-застосунок для тестування розміщення даних на картці (побудовано з дійсного коду з домогою emsdk)
- Автоматична поправка на літній час
- Перевірено програмування і конфігурування у Windows, додано інструкції
- Аргументи до sync-clock.py для зміни послідовного порту і виконання скрипту команд
- Модель станції в OpenSCAD і запропоновано кріплення

### Змінено

- **Нову структуру даних**, стійку до втрати інформації через невдалий запис деяких карток
- Використано зовнішній EEPROM AT24C32 на платі годинника DS3231
- Виправлено обчислення затримки в sync_clock.py, явне очікування на запрошення
- Виправлено розміщення на екрані додатку Android для менших екранів
- Зберігати вікно при обертанні екрана
- Виправлено місткість картки
- Виправлено крах, коли сміття в часовій відмітці
- Дозволено введення ключа шітснадцядковими цифрами нижнього регістру
- Не записувати дубльовану відмітку на станції

## [1.1.0] - 2024.02.24

### Додано

- Випробування попередніх ключів у Android для спрощення підготовки і скидання карток
- Блокування зміну адреси вивантаження для запобігання випадкового змінювання
- Підтвердження успішного запуску (OK = --- -.-)
- Встановлення дати і часу з допомогою таймштампу UNIX
- Період утримання журналу відміток (кількість днів)

### Змінено

- Виправлено вивантаження фінішного КП: вивантажувати не потрібно, номер має бути 900 в QuickEvent
- Виправлено стартовий час по *останній* відмітці старту
- Створено прототип корпусу з входом для заряджання, вимикачем і конектором для програматора
- Виправлено DNF, якщо немає відмітки про фініш (finishTime = 0xEEEE)
- Використання годинника Arduino для мілісекундної точності при синхронізації годинника

### Видалено

- Батарейки з BOM (може бути повторно використана з е-цигарок)
- Вимірювання часу з довільної точки, завжди з початку доби
- Засинання після періоду затишшя, потрібно користуватися кнопкою вимкнення

## [1.0] - 2024-01-27

### Додано

- Перші 10 прототипів з відкритим корпусом

[Невипущене]: https://github.com/sakhnik/arduin-o-punch/compare/v2.1.0...HEAD
[2.1.0]: https://github.com/sakhnik/arduin-o-punch/compare/v2.0.0...v2.1.0
[2.0.0]: https://github.com/sakhnik/arduin-o-punch/compare/v1.1.0...v2.0.0
[1.1.0]: https://github.com/sakhnik/arduin-o-punch/compare/v1.0...v1.1.0
[1.0]: https://github.com/sakhnik/arduin-o-punch/releases/tag/v1.0

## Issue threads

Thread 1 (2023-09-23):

[arduino] Visual confirmation

sakhnik, 2023-09-23:
Add a LED, blink on successful operation (punching, configuration etc). A distinctive signal should be produced for failure.

Closed 2023-09-30.

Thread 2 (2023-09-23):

[arduino] Audible confirmation

sakhnik, 2023-09-23:
Add piezo buzzer to produce positibe/negative confirmation when punching, configuring etc.

Closed 2023-09-30.

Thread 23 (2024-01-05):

Release android app to F-Droid

sakhnik, 2024-01-05:
It'll have to be run on a couple of devices simultaneously.

sakhnik, 2024-01-13:
Will use own web site https://sakhnik.com/aop.apk

Closed 2024-01-13.

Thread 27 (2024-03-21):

Investigate and fix serial input handling in esp32

sakhnik, 2024-03-21:
serialEvent() doesn't work. Instead, I have to poll the serial for input for now.

sakhnik, 2024-05-01:
Not an issue

Closed 2024-05-01.

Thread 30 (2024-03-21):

[ESP32] Battery usage optimization

sakhnik, 2024-03-21:
Can we scale the CPU down to 10 MHz? How to do that dynamically? How much current is drawn from the battery?

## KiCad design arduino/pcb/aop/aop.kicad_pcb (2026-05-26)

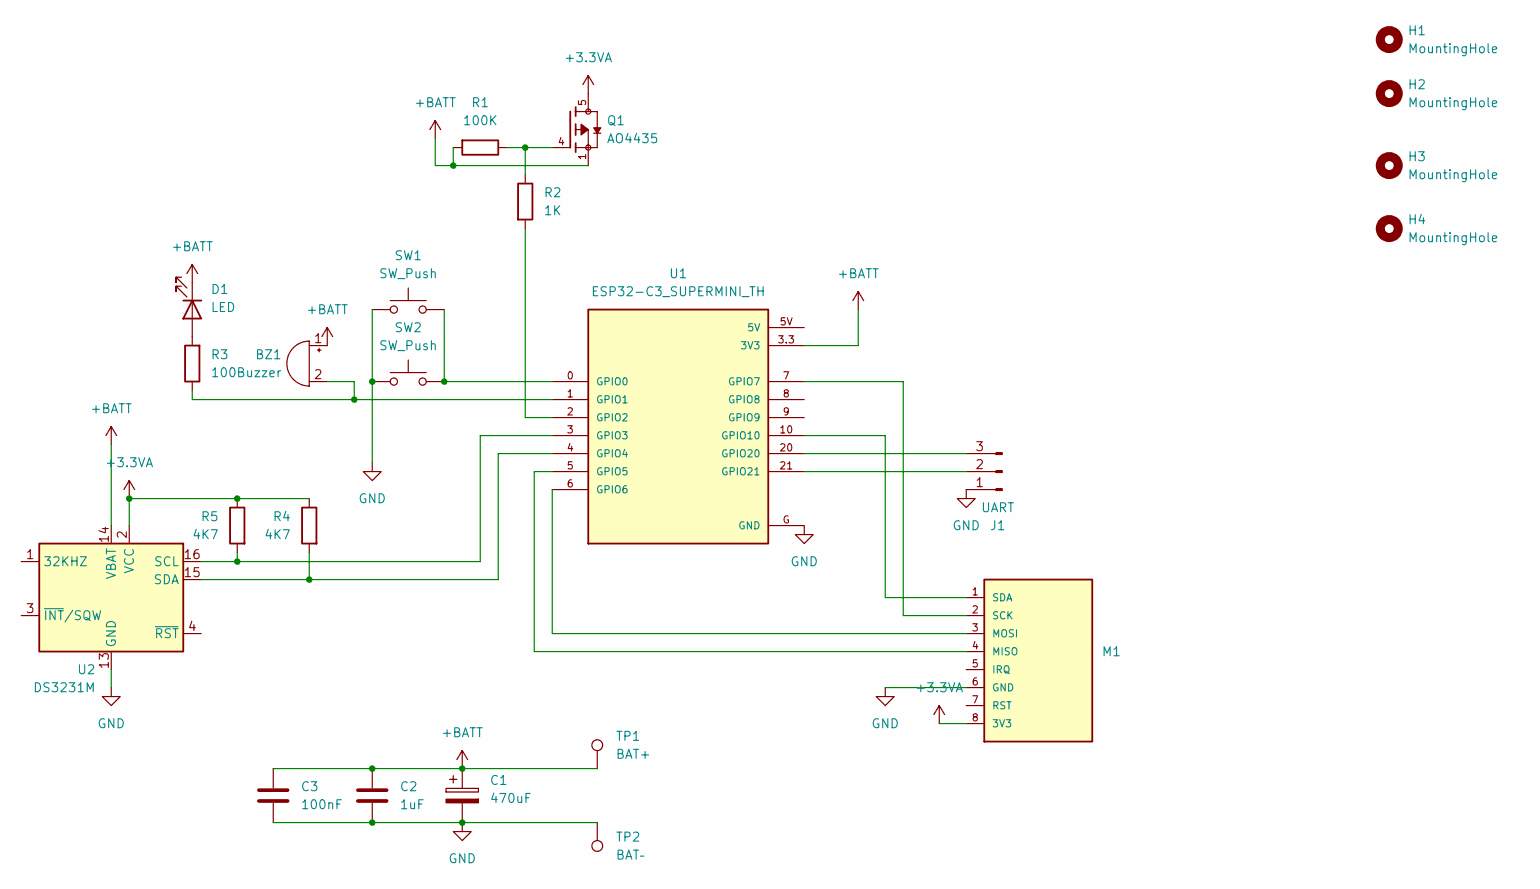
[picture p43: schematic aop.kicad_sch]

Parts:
BZ1: Buzzer; Buzzer_12x9.5RM7.6
C1: 470uF; CP_Radial_D8.0mm_P3.50mm
C2: 1uF; C_1206_3216Metric
C3: 100nF; C_1206_3216Metric
D1: LED; LED_1206_3216Metric
H1, H2, H3, H4: MountingHole; MountingHole_2.2mm_M2
J1: UART; PinHeader_1x03_P2.54mm_Vertical
M1: RFID-RC522_1; MPN RFID-RC522
Q1: AO4435; SOIC127P600X175-8N
R1: 100K; R_1206_3216Metric
R2: 1K; R_1206_3216Metric
R3: 100; R_1206_3216Metric
R4, R5: 4K7; R_1206_3216Metric
SW1: SW_Push; R_Axial_DIN0207_L6.3mm_D2.5mm_P5.08mm_Vertical
SW2: SW_Push; R_Axial_DIN0207_L6.3mm_D2.5mm_P15.24mm_Horizontal
TP1: BAT+; TestPoint_THTPad_4.0x4.0mm_Drill2.0mm
TP2: BAT–; TestPoint_THTPad_4.0x4.0mm_Drill2.0mm
U1: ESP32-C3_SUPERMINI_TH; MODULE_ESP32-C3_SUPERMINI_TH
U2: DS3231M; SOIC-16W_7.5x10.3mm_P1.27mm

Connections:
+3.3VA: M1.8 (3V3), Q1.5, Q1.6, Q1.7, Q1.8, R4.1, R5.1, U2.2 (VCC)
+BATT: BZ1.1 (+), C1.1, C2.1, C3.1, D1.1 (K), Q1.1, Q1.2, Q1.3, R1.2, TP1.1 (1_1), U1.3.3 (3V3), U2.14 (VBAT)
GND: C1.2, C2.2, C3.2, J1.1, M1.6 (GND), SW1.1, SW2.1, TP2.1 (1_1), U1.G (GND), U2.5 (GND), U2.6 (GND), U2.7 (GND), U2.8 (GND), U2.9 (GND), U2.10 (GND), U2.11 (GND), U2.12 (GND), U2.13 (GND)
unnamed: BZ1.2 (-), R3.1, U1.1 (GPIO1)
unnamed: D1.2 (A), R3.2
unnamed: J1.2, U1.21 (GPIO21)
unnamed: J1.3, U1.20 (GPIO20)
unnamed: M1.4 (MISO), U1.5 (GPIO5)
unnamed: M1.3 (MOSI), U1.6 (GPIO6)
unnamed: M1.2 (SCK), U1.7 (GPIO7)
unnamed: M1.1 (SDA), U1.10 (GPIO10)
unnamed: Q1.4, R1.1, R2.1
unnamed: SW1.2, SW2.2, U1.0 (GPIO0)
unnamed: R2.2, U1.2 (GPIO2)
unnamed: R5.2, U1.3 (GPIO3), U2.16 (SCL)
unnamed: R4.2, U1.4 (GPIO4), U2.15 (SDA)

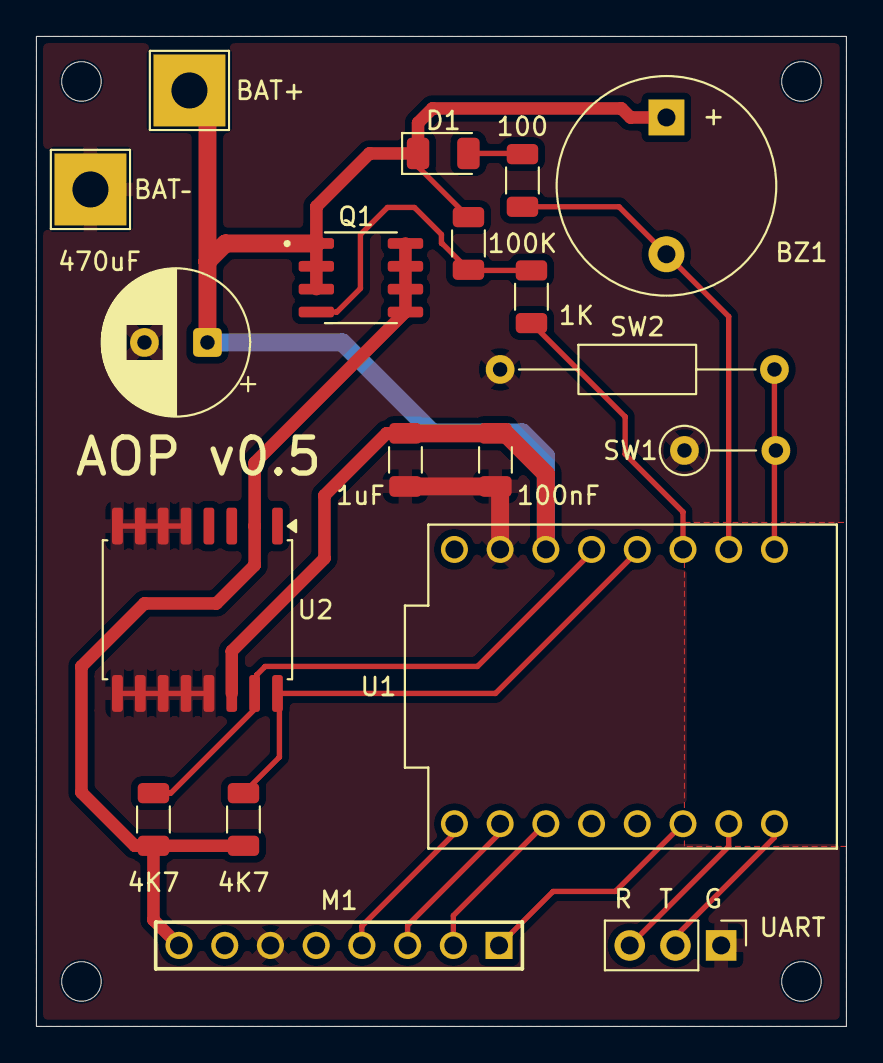
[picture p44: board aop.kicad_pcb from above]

Board: 2 copper layers, 45.0 x 55.0 mm, 23 parts (0 on the bottom side), 16 nets.

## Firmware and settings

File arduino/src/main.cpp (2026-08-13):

#include "Buzzer.h"
#include "Settings.h"
#include "Shell.h"
#include "Bluetooth.h"
#include "Network.h"
#include "OutMux.h"
#include "Operation.h"
#include "RtcLog.h"

Buzzer buzzer;
Settings settings{buzzer};
OutMux outMux;
Shell shell{outMux, settings, buzzer};

Bluetooth bluetooth{outMux, settings, shell};
Network network{outMux, settings, shell, buzzer};
Operation operation{buzzer, settings, outMux, bluetooth, network};

void setup()
{
    RtcLog::Init();

    Serial.begin(115200);

    buzzer.Setup();

    if (operation.Setup() || settings.Setup()) {
        while (true) {
            vTaskDelay(pdMS_TO_TICKS(1000));
            Serial.println(F("Failed to initialize"));
        }
    }

    bool initialization_ok = true;

    if (settings.IsKeyDefault()) {
        buzzer.SignalDefaultKey();
        initialization_ok = false;
    }

    shell.Setup();
    shell.SetOperation(&operation);
    bluetooth.Setup();
#if defined(ENABLE_WIFI) && ENABLE_WIFI
    network.Setup();
#endif

    operation.SetupLate();

    if (initialization_ok) {
        buzzer.SignalOk();
    }
}

void loop()
{
    // Check the serial for input and prohibit light sleep while the serial is active.
    while (Serial.available()) {
        auto ch = Serial.read();
        if (0 < ch && ch < 0xf0) {
            shell.PutChar(ch);
            operation.TransitionToActive();
        }
    }

    operation.Loop();
}

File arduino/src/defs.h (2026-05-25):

#pragma once

#define WAKEUP_PIN 0
#define BUZZER_PIN 1
#define MOSFET_PIN 2

#define I2C_SCL 3
#define I2C_SDA 4

#define SPI_MISO 5
#define SPI_MOSI 6
#define SPI_SCK 7
#define SPI_SS 10

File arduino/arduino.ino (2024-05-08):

#include "defs.h"
#include "Buzzer.h"
#include "Context.h"
#include "Puncher.h"
#include "Shell.h"
#ifdef ESP32
#  include "Bluetooth.h"
#  include "Network.h"
#endif //ESP32
#include "OutMux.h"

Buzzer buzzer;
Context context{buzzer};
Puncher puncher{context};
OutMux outMux;
Shell shell{outMux, context, buzzer};

#ifdef ESP32

enum OperationMode
{
    OM_NORMAL = 0,
    OM_BLUETOOTH,
    OM_WIFI,

    OM_MODE_COUNT
};
OperationMode operation_mode = OM_NORMAL;

Bluetooth bluetooth {outMux, context, shell};
Network network {outMux, context, shell, buzzer};

#endif //ESP32

void setup()
{
    pinMode(LED_CONFIRM_PIN, OUTPUT);
    pinMode(BUZZER_PIN, OUTPUT);

    // 9600 allows for reliable communication with automated scripts like sync-clock.py
    Serial.begin(9600);

#ifdef ESP32
    // Set the CPU frequency to 40 MHz for power optimization
    setCpuFrequencyMhz(40);
    Serial.print(F("CPU Frequency: "));
    Serial.print(getCpuFrequencyMhz());
    Serial.println(F(" MHz"));
#endif //ESP32

    buzzer.Setup();

    if (context.Setup()) {
        while (true)
            buzzer.Tick();
    }

    bool initialization_ok = true;

    if (context.IsKeyDefault()) {
        buzzer.SignalDefaultKey();
        initialization_ok = false;
    }

    puncher.Setup();
    shell.Setup();
#ifdef ESP32
    bluetooth.Setup();
    network.Setup();
#endif

    if (initialization_ok) {
        buzzer.SignalOk();
    }
}

// Don't loop here to make sure serialEvent() is processed.
void loop()
{
    auto now = millis();

    auto res = puncher.Punch();
    if (!res) {
        buzzer.ConfirmPunch();
    }

    if (res == ErrorCode::CARD_IS_FULL) {
        buzzer.SignalCardFull();
    }

#ifdef ESP32
    if (res == ErrorCode::SERVICE_CARD) {
        AdvanceOperationMode();
    }
#endif //ESP32

    buzzer.Tick();
    shell.Tick();
#ifdef ESP32
    shell.OnSerial();
    bluetooth.Tick();
    network.Tick();
#endif
}

#ifdef ESP32
void AdvanceOperationMode()
{
    switch (operation_mode) {
    case OM_BLUETOOTH:
        bluetooth.SwitchOff();
        break;
    case OM_WIFI:
        network.SwitchOff();
        break;
    }
    operation_mode = static_cast<OperationMode>((operation_mode + 1) % OM_MODE_COUNT);
    switch (operation_mode) {
    case OM_NORMAL:
        buzzer.SignalOk();
        break;
    case OM_BLUETOOTH:
        buzzer.SignalBluetooth();
        bluetooth.SwitchOn();
        break;
    case OM_WIFI:
        // It takes a second or so to initialize WiFi. The CPU will be busy.
        // Play a confirmation melody only after that to avoid distortion.
        network.SwitchOn();
        buzzer.SignalWifi();
        break;
    }
}
#endif //ESP32

#ifdef ARDUINO_AVR_PRO
void serialEvent()
{
    shell.OnSerial();
}
#endif //ARDUINO_AVR_PRO

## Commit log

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2023-09-15 Port card punching to c++ for arduino
2023-09-16 Organize arduino and test build
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2023-09-21 Add arduino-timer library, which will be useful for delayed tasks
2023-09-25 Light a confirmation led
2023-09-27 Add active buzzer for audible confirmation
    [arduino.ino, defs.h]
2023-10-05 Fix #6 Configure station with the actual encryption key, collect clock calibration information
    [Puncher.cpp, arduino.ino]
2023-10-08 Fix #3 Upload readout to QuickEvent
    [Puncher.cpp]
2023-10-14 Add a checksum to the header, a class for error codes
    [Puncher.cpp]
2023-10-16 Clear a card in Arduino too #13
2023-10-20 Android: use background thread instead of GlobalContext
2023-10-23 Extract buzzer into own class, confirm key change
    [Buzzer.cpp, Shell.cpp, arduino.ino]
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2023-10-27 Arduino: forcibly clear the card at check and start station
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2023-11-12 Start working on enclosure box
    [box.FCStd]
2023-11-13 Start adding holes
    [box.FCStd]
2023-11-13 Place arduino
    [box.FCStd]
2023-11-14 Place RTC, add a hole for battery charger
    [box.FCStd]
2023-11-15 Split the box into multiple parts
    [box.FCStd]
2023-11-16 Prepare laser cut interlocks (try 1)
    [box.FCStd]
2023-11-18 Remove all holes, use glue to fix components, add notches for opening
    [box.FCStd]
2023-11-22 Increase length and width
    [box.FCStd]
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2023-11-27 Use plastic box Z77, more materials for the prototype
2023-11-28 Order arduino pro mini and buzzers for prototypes
2023-12-03 Fix sleep mode initiation too soon
    [Puncher.cpp, arduino.ino]
2023-12-04 Fix rounding error => no sleep
    [arduino.ino]
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2023-12-04 Remove custom enclosure in favour of Z77, remove Nano motherboard
    [box.FCStd]
2023-12-06 Fix #16: synchronize the clock on the second edge, serial initialization
    [sync-clock.py]
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2023-12-11 Play morse codes for confirmation and failures #4
    [Buzzer.cpp]
2023-12-11 Fix #4 Update docs
    [Buzzer.cpp]
2023-12-11 Fix #11 Indicate full card with Morse F
    [Buzzer.cpp, arduino.ino]
2023-12-13 Fix #18 Make timeout hours configurable in cli
    [Shell.cpp, arduino.ino]
2023-12-14 Fixup #18: fix timeout calculation
    [arduino.ino]
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2023-12-15 Fix #4 Enqueue the outstanding melodies into a circular buffer
    [Buzzer.cpp]
2023-12-19 Fix #20 Add CLI commands to format and query the recorder
    [Shell.cpp]
2023-12-20 Ordered 10 boxes Z-77 with new price, updated the BOM
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2023-12-21 Fix #21 Remove service card support: use CLI for configuration
    [Puncher.cpp]
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2024-01-12 Document station id, encryption key, clock synchronization sample #22
2024-01-12 Fix заходів -> підходів #22
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2024-02-03 Update BOM: exclude battery (reusing wape batteries), add connectors
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2024-02-15 Update BOM with round switch and round DC in
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2024-02-17 Fix #24 Implement record retaining period in days
    [Shell.cpp]
2024-02-18 Fix timezone issues, allow printing timestamp
    [Shell.cpp, sync-clock.py]
2024-02-19 Revert "Increase sleeping time to 8 seconds"
    This reverts commit b15ce90136ac4dfcd56f1eed093d4ebbc5af2fc5.
    [arduino.ino]
2024-02-19 Revert "Power RC522 from Arduino IO pin"
    This reverts commit 7fd3e8fb91b98b6d5c7aa6a58cf0492023676a42.
    [Puncher.cpp, defs.h]
2024-02-19 Remove low power sleep in favour of power switch button
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2024-02-26 Improve sync-clock.py reliability when a station is reset
    [sync-clock.py]
2024-02-26 Fix clock sync when arduino isn't reset
    [sync-clock.py]
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2024-03-01 Fix the capacity amount
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2024-03-04 Allow entering key with lower case hexa digits
2024-03-04 Allow negative timestamp differences in case the stations aren't synchronous
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2024-03-05 Revert "Print test execution in gradle"
    This reverts commit d97925c9af982436b8b9df262ef7168d4d491c98.
2024-03-09 Test compatibility of Android and Arduino with CLI
2024-03-09 Skip Arduino test execution in Android
2024-03-15 Order more spare parts and esp32 for prototyping
2024-03-20 Skip recording a duplicate punched card on the station, print error codes
    [Puncher.cpp]
2024-03-20 Track carefully whether a punch wasn't confirmed to have accurate record
2024-03-20 Fix formatting of punches in the serial log
    [Puncher.cpp]
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2024-04-07 Add OpenSCAD model of the station
    [station.scad]
2024-04-07 Add battery indicator
    [station.scad]
2024-04-07 Try designing a mount for the station
    [mount.scad, station.scad]
2024-04-08 Add an apron to the mount
    [mount.scad]
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2024-05-04 Skip key in `info`
    [Network.cpp, Shell.cpp]
2024-05-05 Fix buzzer while initializing WiFi #35
    [arduino.ino]
2024-05-08 Fix build in Arduino Pro Mini #35
2024-05-09 Fix promp printing via TCP #35
    [Shell.cpp]
2024-05-09 Partially revert prompt detection #35
    Sync-clock.py brokent
    [Shell.cpp]
2024-05-10 Fix sync-clock.py to work via TCP #35
    [connection.py, sync-clock.py]
2024-05-16 Fix version insertion #44
2024-05-19 Add a button to show the record #42
2024-05-20 Fix #39 Add favicon
    [Network.cpp]
2024-06-06 Fix #40 Implement clock synchronization in web ui
    [Network.cpp]
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2024-11-18 Fix race when handling mifare, use fixed thread pool executor #48
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2025-11-13 Arduino: soft reset MFRC522 periodically
    [Puncher.cpp]
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2025-11-13 [Arduino] Fix esp32 build because of platform development
2025-11-15 [Arduino] Soft reset 522 only when the buzzer is idle
    [Buzzer.cpp, Puncher.cpp]
2025-12-14 [PCB] Start capturing schematics
    [aop.kicad_pcb, aop.kicad_sch]
2025-12-15 PCB: start tracing
    [aop.kicad_pcb, aop.kicad_sch]
2025-12-17 One-sided tracing
    [aop.kicad_pcb]
2025-12-19 Ordered PCB v0.2
    [aop.kicad_pcb]
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2025-12-29 Try two-layer PCB
    [aop.kicad_pcb, aop.kicad_sch]
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2026-02-25 [arduino] Port Buzzer to FreeRTOS
    [Buzzer.cpp, main.cpp]
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2026-02-27 [arduino] Use Serial.onEvent() to avoid polling
    [Shell.cpp, main.cpp]
2026-02-27 [arduino] Rename BuzzerTask to buzzer
    [Buzzer.cpp, Shell.cpp]
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2026-03-01 [arduino] Fix i2c pins sleep
    [defs.h, main.cpp]
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2026-03-02 [arduino] Reconfigure led and buzzer pins to activate on pull down (sleep optimization)
    [Buzzer.cpp, main.cpp]
2026-03-03 [arduino] Update schematics
    [aop.kicad_sch]
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2026-03-03 Revert "Try i2c for rc522"
    This reverts commit 8de5255e3949c01a925d255cc2681ecb0f1bd34a.
    [defs.h, main.cpp]
2026-03-07 [arduino] Configure high impedance state for I2C and SPI => 0.3 mA
2026-03-12 [arduino] Initialize buzzer immediately after the startup
    [main.cpp]
2026-03-12 [arduino] Store config in preferences instead of EEPROM
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2026-03-12 [arduino] Fix wrong field restoring from the preferences
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2026-03-12 [arduino] Skip I2C altogether
    [main.cpp]
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2026-03-15 Remove DS3231
    [aop.kicad_sch]
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2026-03-18 [pcb] Add one more wakeup switch
    [aop.kicad_sch]
2026-03-21 [pcb] AOP v0.1
    [aop.kicad_pcb, aop.kicad_sch]
2026-03-21 [arduino] Rework bluetooth for NimBLE
    [Bluetooth.cpp]
2026-03-22 [arduino] Switch CPU frequency in the control task
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2026-03-23 [pcb] Cut a proper slit for the mc
    [aop.kicad_pcb]
2026-03-23 [arduino] Fix memory leak in BLE
    [Bluetooth.cpp]
2026-03-24 [arduino] Fix heap corruption
    [Bluetooth.cpp]
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2026-03-25 [arduino] Slow down BLE transmission to avoid loosing data
    [Bluetooth.cpp]
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2026-03-25 [arduino] Add a RAII mutex modelled after STL
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2026-03-26 [arduino] Reset BLE characteristic callbacks to avoid heap corruption
    [Bluetooth.cpp]
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2026-03-26 [arduino] Protect the rest of the config params
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2026-04-19 [pcb] Restore through-hole esp32-c3
    [aop.kicad_pcb]
2026-04-19 [pcb] Increase the length
    [aop.kicad_pcb, aop.kicad_sch]
2026-04-19 [arduino] Configure active and eco time in the web UI
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2026-04-20 [pcb] Prepare 0.2 for fabrication
    [aop.kicad_pcb, aop.kicad_sch]
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2026-04-20 [arduino] Fix a crash when changing a setting when BLE is active
    [Bluetooth.cpp]
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2026-04-22 [arduino] Wake up for 2 minutes only (unless a card is punched), don't account service card
2026-04-23 [arduino] Add a reset reason logger
    [Operation.cpp, Shell.cpp, main.cpp]
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2026-04-24 [arduino] Write diagnostic information to the debug card
2026-04-25 [pcb] Stabilize power rail with capacitors
    [aop.kicad_pcb, aop.kicad_sch]
2026-04-27 [pcb] Prepare for fabrication
    [aop.kicad_pcb]
2026-05-02 [arduino] Restore RTC DS3231 for better precision, connect to pins 10 and 20
    The pin 9 is used for boot and it's pulled up in hardware. Bad for deep
    sleep charge economy.
2026-05-02 [pcb] Add DS3231
    [aop.kicad_pcb, aop.kicad_sch]
2026-05-03 [pcb] Choose closer pins for SPI
    [aop.kicad_pcb, aop.kicad_sch]
2026-05-03 [pcb] Reroute to improve ground plane continuity
    [aop.kicad_pcb, aop.kicad_sch]
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2026-05-05 [pcb] Send v0.4 for fabrication
    [aop.kicad_pcb]
2026-05-24 [pcb] Move SDA to GPIO4 to avoid clash with UART
    [aop.kicad_pcb, aop.kicad_sch]
2026-05-24 [pcb] Use GPIO20 for SPI_SS because GPIO8 is high in the deep sleep
    [aop.kicad_pcb, aop.kicad_sch]
2026-05-25 [pcb] Rearrange pins, combine buzzer and led to free UART
    [aop.kicad_pcb, aop.kicad_sch]
2026-05-25 [pcb] Expose UART0
    [aop.kicad_pcb, aop.kicad_sch]
2026-05-26 [pcb] Send v0.5 for fabrication
    [aop.kicad_pcb]
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2026-06-24 [arduino] Transition to active state when there's serial input
2026-06-24 [arduino] Fix stats printout
    [Operation.cpp]
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2026-06-25 Refactor AOP lib to get rid of Arduino headers
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2026-06-27 Throttle card operations when formatting and reading out
2026-06-27 Remove message about failed auth
    [Puncher.cpp]
2026-06-30 Print debug info when reading out a debug card
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2026-07-26 Fix card corruption when clearing in Arduino
2026-07-29 Add a new case
    [case.scad]
2026-07-29 Move enclosure into own directory
    [aop.scad]
2026-07-30 Adjust the enclosure
    [aop.scad]
2026-07-31 Rotate the pcb to move LED to the edge
    [aop.scad]
2026-07-31 Fix wifi mode immediate timeout
    [Network.cpp]
2026-08-03 Add central screws, try pcb notches, adjust some positions
    [aop.scad]
2026-08-04 Tighten tolerances
    [aop.scad]
2026-08-12 Autodetect which device to update with BLE OTA
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2026-08-13 Keep testing MFRC522 after the failure
    [Puncher.cpp]
2026-08-13 Set i2c pins separately from begin() because libraries can call begin() too
2026-08-13 Restore default uart0 because it allows early RTC failure reporting
2026-08-15 Add an optional cable hole
    [aop.scad]
2026-08-20 Add a dock connector for charging
    [dock.scad]
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2026-08-21 Update BOM.md: add buzzer link
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2026-09-27 Use distinctive signal for wake up and power on
